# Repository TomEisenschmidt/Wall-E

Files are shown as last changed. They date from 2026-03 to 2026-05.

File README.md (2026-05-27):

# Projet IOT MAKER

L'objectif de ce projet est de réaliser un robot intéractif en modélisant les pièces en 3D et en utilisant des composants arduino pour gérer la partie intelligente.

## Fonctionnalitées : 

Wall E peut :
- Se déplacer
- Ouvrir et fermer sa trappe
- Déplacer ses bras d'avant en arrière
- Afficher des informations sur son écran

## Matériel : 

- 2 moteurs DC
- 1 carte de contrôle moteur L298N
- 4 batteries 18650
- 2 servo-moteur SG90
- 1 servo-moteur MG996R
- 1 capteur ultrason HC-SR04
- 1 écran LCD

## Impression 3D

- Face avant du robot (espace vide pour la porte), contient le servo de la porte
- Porte avant
- Face arrière
- Plaque gauche
- Plaque droite
- Sol
- Plaque du haut
- Tête
- Cache moteurs
- Support pour les roues non motrices

## Approche de la conception

Le projet repose sur sa composante modulable.
En effet, les différentes parties sont fixés entre elles grâce à des vis M4, permettant de démonter et modifier certaines parties facilement.
La face avant contient la porte et se visse au sol et les plaques droite/gauche se vissent à la face avant/arrière.
La seule exception repose pour les parties en dessous du robot et la tête, celles-ci sont fixées à l'aide de colle forte (élément non destiné à être changés).

Ainsi, cette approche permet la modification et le dépannage facile en permettant de démonter les plaques du chassis centrales contenant les différents composants.

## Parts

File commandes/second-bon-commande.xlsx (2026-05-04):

Amazon |  |  |  |  |  | Gotronic |  |  |  |  | Conrad
Composant | Lien | Quantité | Prix/Unitaire | Total/produit |  | Composant | Lien | Quantité | Prix/Unitaire | Total/produit | Composant | Lien | Quantité | Prix/Unitaire | Total/produit
M4 Vis Boulons et Écrous et Rondelles Set | Kit_Vis (https://www.amazon.fr/Boulons-Rondelles-Hexagonale-Inoxydable-Assortiment/dp/B0DQTTY82R) | 1 | 10.99 | 10.99 |  | Servo Moteur Linéaire | servomoteur-lineaire (https://www.gotronic.fr/art-servomoteur-lineaire-2595-30098.htm) | 2 | 9.6 | 19.2 | Carte de dévelopement moteur | Motodriver (https://www.conrad.fr/fr/p/joy-it-sbc-motodriver2-carte-de-developpement-1-pc-s-1573541.html?experience=b2c) | 1 | 5.99 | 5.99
Colle Forte | Colle (https://www.amazon.fr/UHU-Colle-tout-super-transparente/dp/B004QMADSW) | 1 | 3.69 | 3.69 |  | US HC-SR04 | detection-us (https://www.gotronic.fr/art-module-de-detection-us-hc-sr04-20912.htm) | 1 | 3.9 | 3.9 |  |  |  |  | 0
Pince à dénudé | Pince (https://www.amazon.fr/Bosch-Professional-1600A01V03-Chrome-Vanadium-softgrip/dp/B095SV614X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) | 1 | 16.99 | 16.99 |  | Motoréducteur | Moteur (https://www.gotronic.fr/art-motoreducteur-2-axes-3487-27384.htm) | 2 | 41.5 | 83 |  |  |  |  | 0
Support HC-SR04 | Support Capteur US (https://www.amazon.fr/Support-montage-capteur-ultrasons-intelligente/dp/B0848F4BF8) | 1 | 5.91 | 5.91 |  | Roues TT | Roues TT (https://www.gotronic.fr/art-roue-tout-terrain-120-mm-dg3cr-12401.htm) | 4 | 7.9 | 31.6 |  |  |  |  | 0
Roue 6,8 cm | roues (https://www.gotronic.fr/art-roues-68x25-mm-49218.htm) | 4 | 2.5 | 10 |  |  |  |  |  | 0 |  |  |  |  | 0
 |  |  |  | 0 |  |  |  |  |  | 0 |  |  |  |  | 0
 |  |  |  | 0 |  |  |  |  |  | 0 |  |  |  |  | 0
 |  |  |  | 0 |  |  |  |  | Total | 137.7 |  |  |  | Total | 5.99
 |  |  |  | 0
 |  |  |  | 0
 |  |  |  | 0
 |  |  |  | 0
 |  |  |  | 0
 |  |  |  | 0
 |  |  | Total | 47.58
 |  |  |  | Total commande : | 191.27

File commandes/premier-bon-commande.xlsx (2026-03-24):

Amazon |  |  |  |  |  | Gotronic |  |  |  |  | Conrad
Composant | Lien | Quantité | Prix/Unitaire | Total/produit |  | Composant | Lien | Quantité | Prix/Unitaire | Total/produit | Composant | Lien | Quantité | Prix/Unitaire | Total/produit
Lot de 2 micro servo moteurs | Amazon (https://www.amazon.fr/HAXIHA-Servomoteur-Num%C3%A9rique-Engrenage-Pr%C3%A9cision/dp/B0F892P2WQ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) | 1 | 13.99 | 13.99 |  | Arduino Mega 2560 (board arduino) | gotronic (https://www.gotronic.fr/art-arduino-mega-2560-a000067-12421.htm) | 1 | 45.6 | 45.6 | Pile | conrad (https://www.conrad.fr/fr/p/voltcraft-vc-li-3-6-3000-pile-rechargeable-speciale-18650-flat-top-li-ion-3-6-v-3000-mah-1-pc-s-2749812.html) | 4 | 6.99 | 27.96
Support de batteries | Amazon (http://www.amazon.fr/GTIWUNG-Support-Batterie-Plastique-Rangement/dp/B08CY5LC8M) | 1 | 9.99 | 9.99 |  | 74HC595 (micro-controller) | gotronic (https://www.gotronic.fr/art-74hc595-10102.htm) | 1 | 3.9 | 3.9 |  |  |  |  | 0
 |  |  |  | 0 |  | Palonnier rond en métal avec vis | gotronic (https://www.gotronic.fr/art-palonnier-rond-25-dents-fk-rp-001-25851.htm) | 2 | 4.5 | 9 |  |  |  |  | 0
 |  |  |  | 0 |  |  |  |  |  | 0 |  |  |  |  | 0
 |  |  |  | 0 |  |  |  |  |  | 0 |  |  |  |  | 0
 |  |  |  | 0 |  |  |  |  |  | 0 |  |  |  |  | 0
 |  |  |  | 0 |  |  |  |  |  | 0 |  |  |  |  | 0
 |  |  |  | 0 |  |  |  |  | Total | 58.5 |  |  |  | Total | 27.96
 |  |  |  | 0
 |  |  |  | 0
 |  |  |  | 0
 |  |  |  | 0
 |  |  |  | 0
 |  |  |  | 0
 |  |  | Total | 23.98
 |  |  |  | Total commande : | 82.48

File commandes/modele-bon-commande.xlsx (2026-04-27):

Amazon |  |  |  |  |  | Gotronic |  |  |  |  | Conrad
Composant | Lien | Quantité | Prix/Unitaire | Total/produit |  | Composant | Lien | Quantité | Prix/Unitaire | Total/produit | Composant | Lien | Quantité | Prix/Unitaire | Total/produit
 |  |  |  | 0 |  |  |  |  |  | 0 |  |  |  |  | 0
 |  |  |  | 0 |  |  |  |  |  | 0 |  |  |  |  | 0
 |  |  |  | 0 |  |  |  |  |  | 0 |  |  |  |  | 0
 |  |  |  | 0 |  |  |  |  |  | 0 |  |  |  |  | 0
 |  |  |  | 0 |  |  |  |  |  | 0 |  |  |  |  | 0
 |  |  |  | 0 |  |  |  |  |  | 0 |  |  |  |  | 0
 |  |  |  | 0 |  |  |  |  |  | 0 |  |  |  |  | 0
 |  |  |  | 0 |  |  |  |  | Total | 0 |  |  |  | Total | 0
 |  |  |  | 0
 |  |  |  | 0
 |  |  |  | 0
 |  |  |  | 0
 |  |  |  | 0
 |  |  |  | 0
 |  |  | Total | 0
 |  |  |  | Total commande : | 0

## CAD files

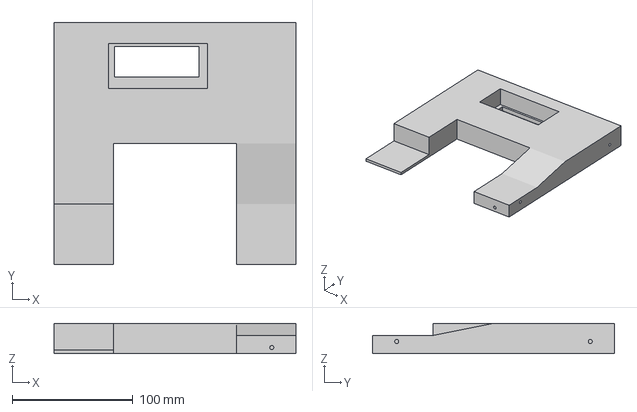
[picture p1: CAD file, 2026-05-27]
stéréolitographie/Bloc Avant & Arrière/Face Avant.3mf
200.0 x 200.0 x 25.0 mm

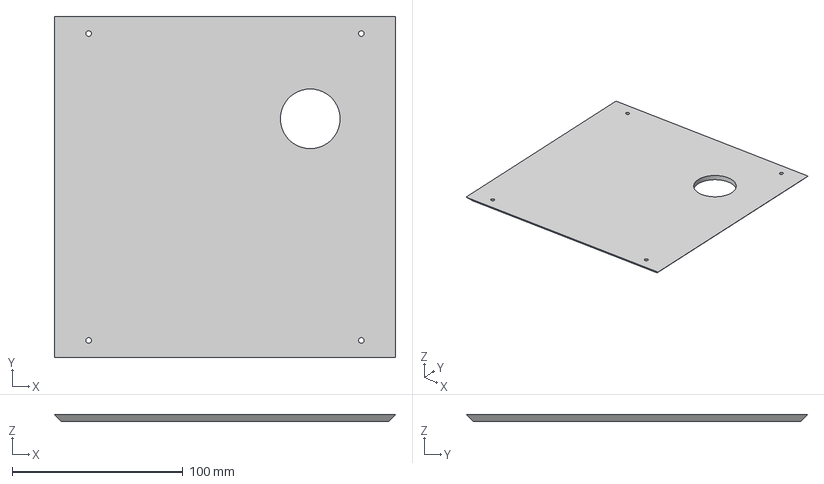
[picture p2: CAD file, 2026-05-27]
stéréolitographie/Bloc Côtés/BBG - 200x200 mm.3mf
200.0 x 200.0 x 4.00 mm

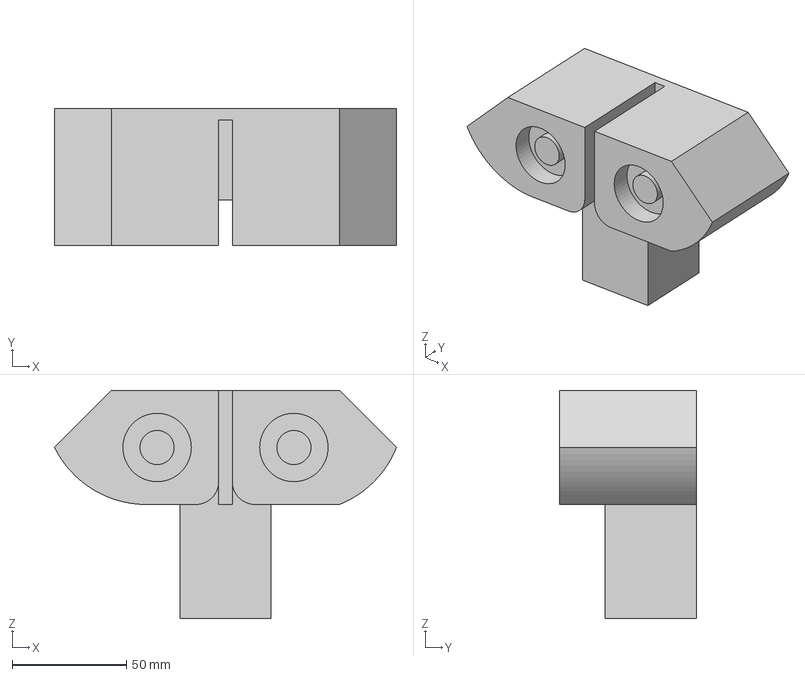
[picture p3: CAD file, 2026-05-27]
stéréolitographie/Bloc Plafond & Tête/Tête.3mf
150.0 x 60.0 x 100.0 mm

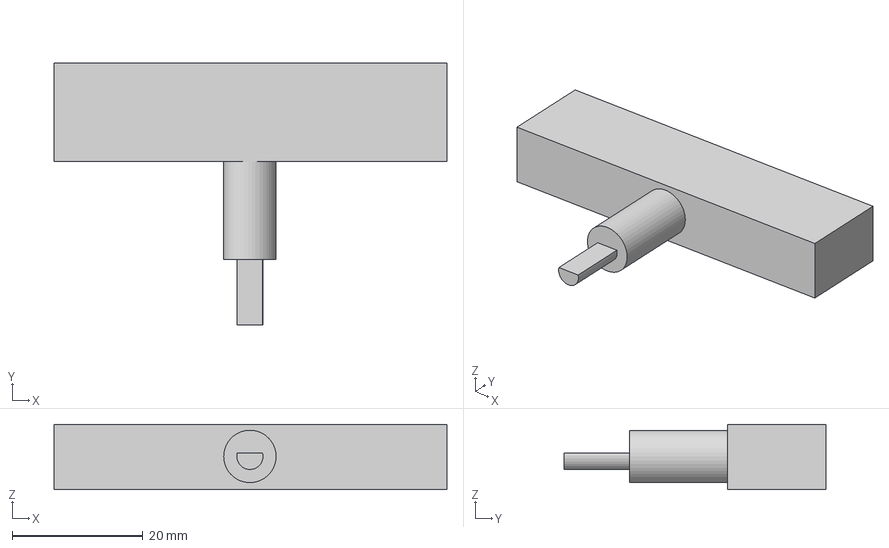
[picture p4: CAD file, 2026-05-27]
stéréolitographie/Bloc Sol & Roues/attache_moteur_4mm_diametres.3mf
60.0 x 40.0 x 10.00 mm

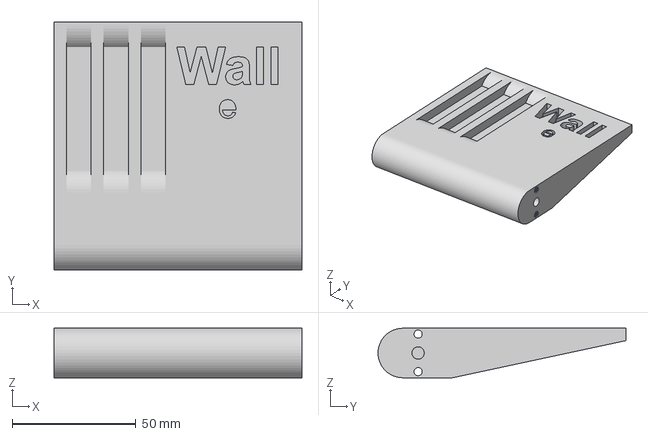
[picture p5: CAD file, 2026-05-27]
stéréolitographie/Bloc Avant & Arrière/Trappe.3mf
100.0 x 100.0 x 20.0 mm

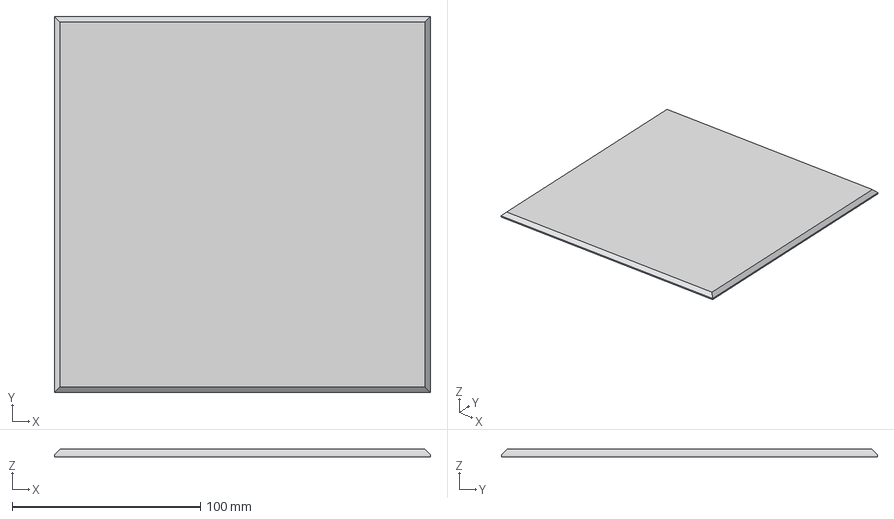
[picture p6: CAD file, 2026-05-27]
stéréolitographie/Bloc Plafond & Tête/plafond 200x200mm.3mf
200.0 x 200.0 x 4.00 mm

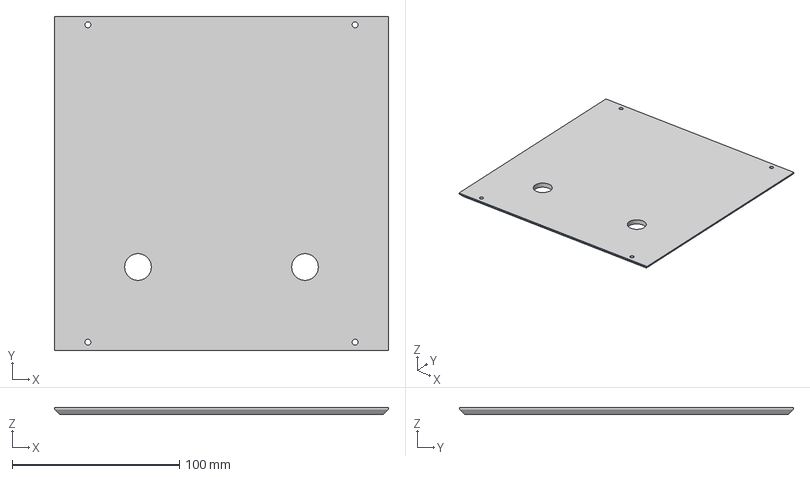
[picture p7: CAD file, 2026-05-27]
stéréolitographie/Bloc Sol & Roues/sol 200x200mm.3mf
200.0 x 200.0 x 4.00 mm

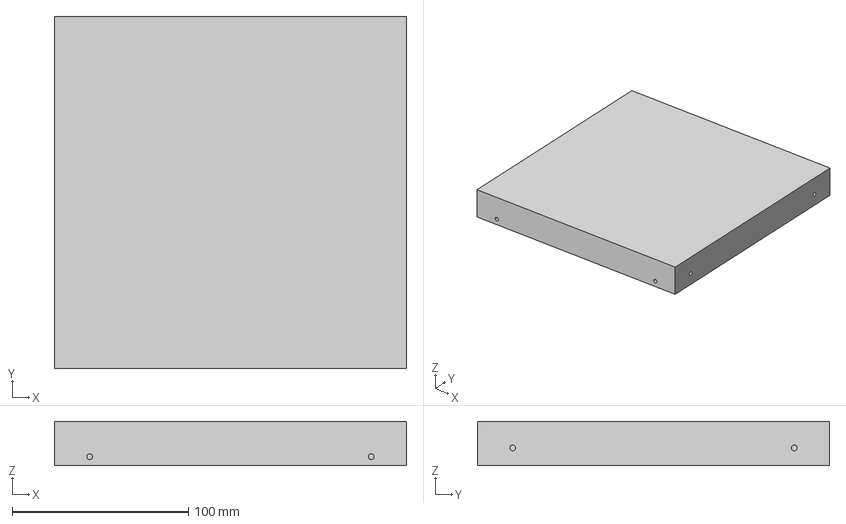
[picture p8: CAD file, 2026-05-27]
stéréolitographie/Bloc Avant & Arrière/Face Arrière.3mf
200.0 x 200.0 x 25.0 mm

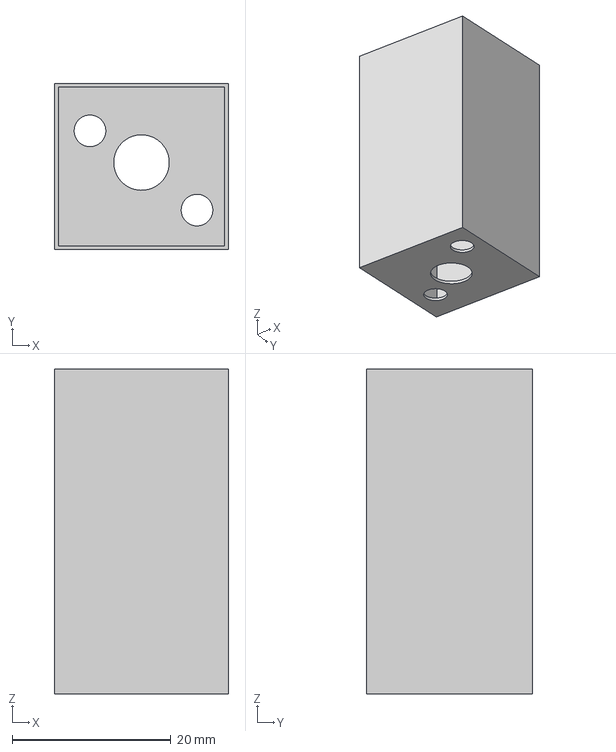
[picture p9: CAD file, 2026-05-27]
stéréolitographie/Bloc Sol & Roues/boitier_moteur_roue.3mf
22.0 x 21.0 x 41.0 mm

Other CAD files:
stéréolitographie/Bloc Côtés/BBD - 200x200 mm.3mf
Front Door 24-03-2026.f3d
Front Door Structure 25-03-2026.f3d
Modèles/Bloc Avant & Arrière/Back Structure.f3d
Modèles/Bloc Avant & Arrière/Front - Door.f3d
Modèles/Bloc Avant & Arrière/Front - Structure.f3d
Modèles/Bloc Bras/BBD - 200x200 mm.f3d
Modèles/Bloc Bras/BBG - 200x200 mm.f3d
Modèles/Bloc Plafond & Tête/plafond 200x200mm.f3d
Modèles/Bloc Plafond & Tête/tete_wall_e.f3d
Modèles/Bloc Sol & Chenille/Sol 200x200mm.f3d
Modèles/Bloc Sol & Chenille/attache_roue_4mm_diametres.f3d
Modèles/Bloc Sol & Chenille/boitier_moteur_roue.f3d
Modèles/Vision globale du cube central.f3d

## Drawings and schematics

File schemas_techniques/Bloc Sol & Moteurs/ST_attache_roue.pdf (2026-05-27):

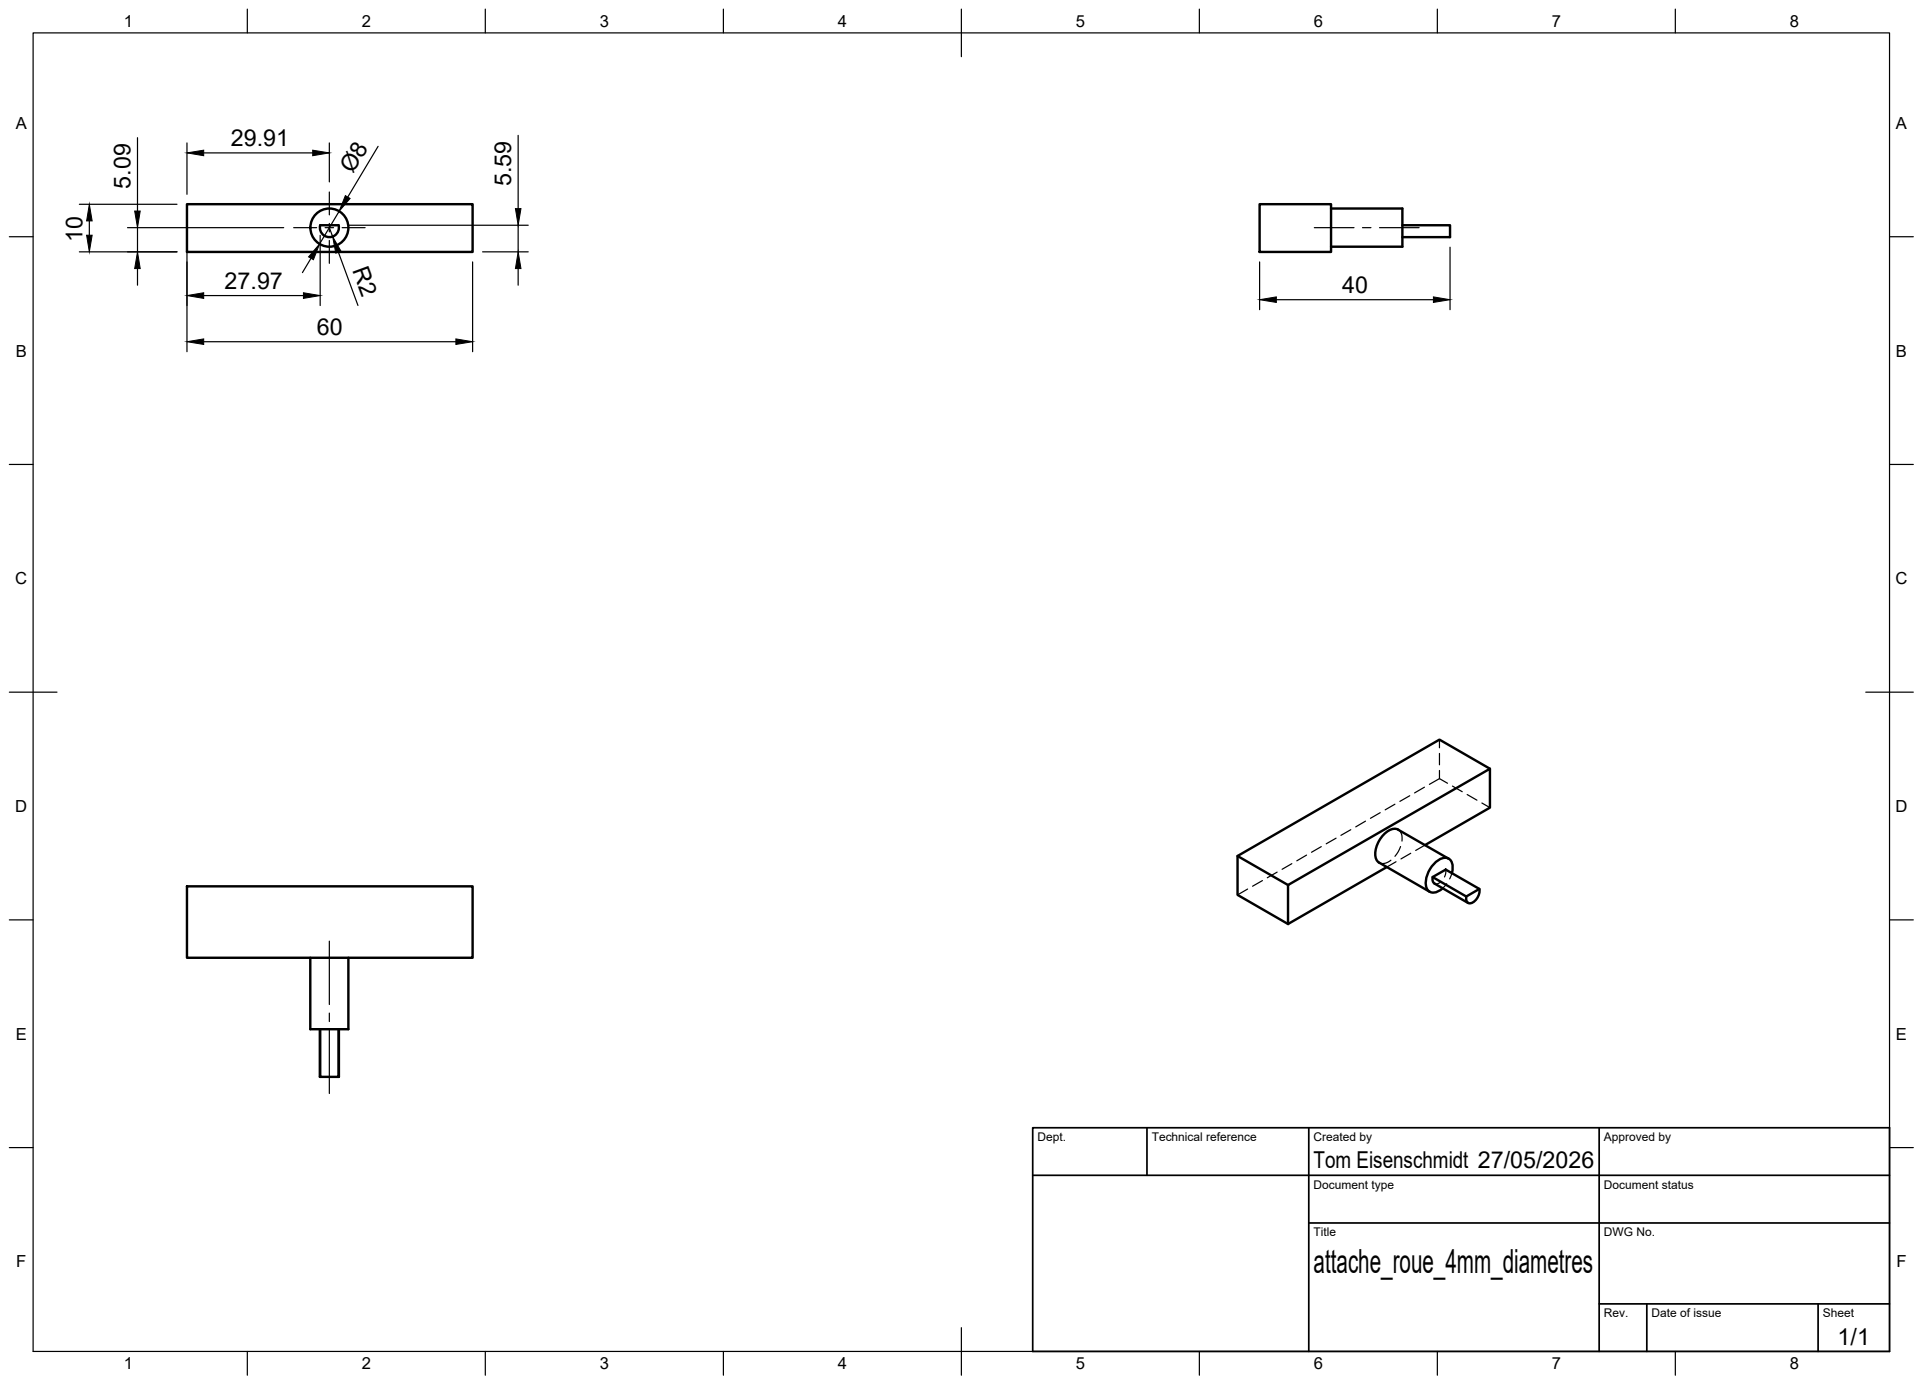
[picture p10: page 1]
Title; DWG No.; Rev.; Date of issue; Sheet

Dept. | Technical reference | Created by Tom Eisenschmidt 27/05/2026 | Approved by

Document type | Document status

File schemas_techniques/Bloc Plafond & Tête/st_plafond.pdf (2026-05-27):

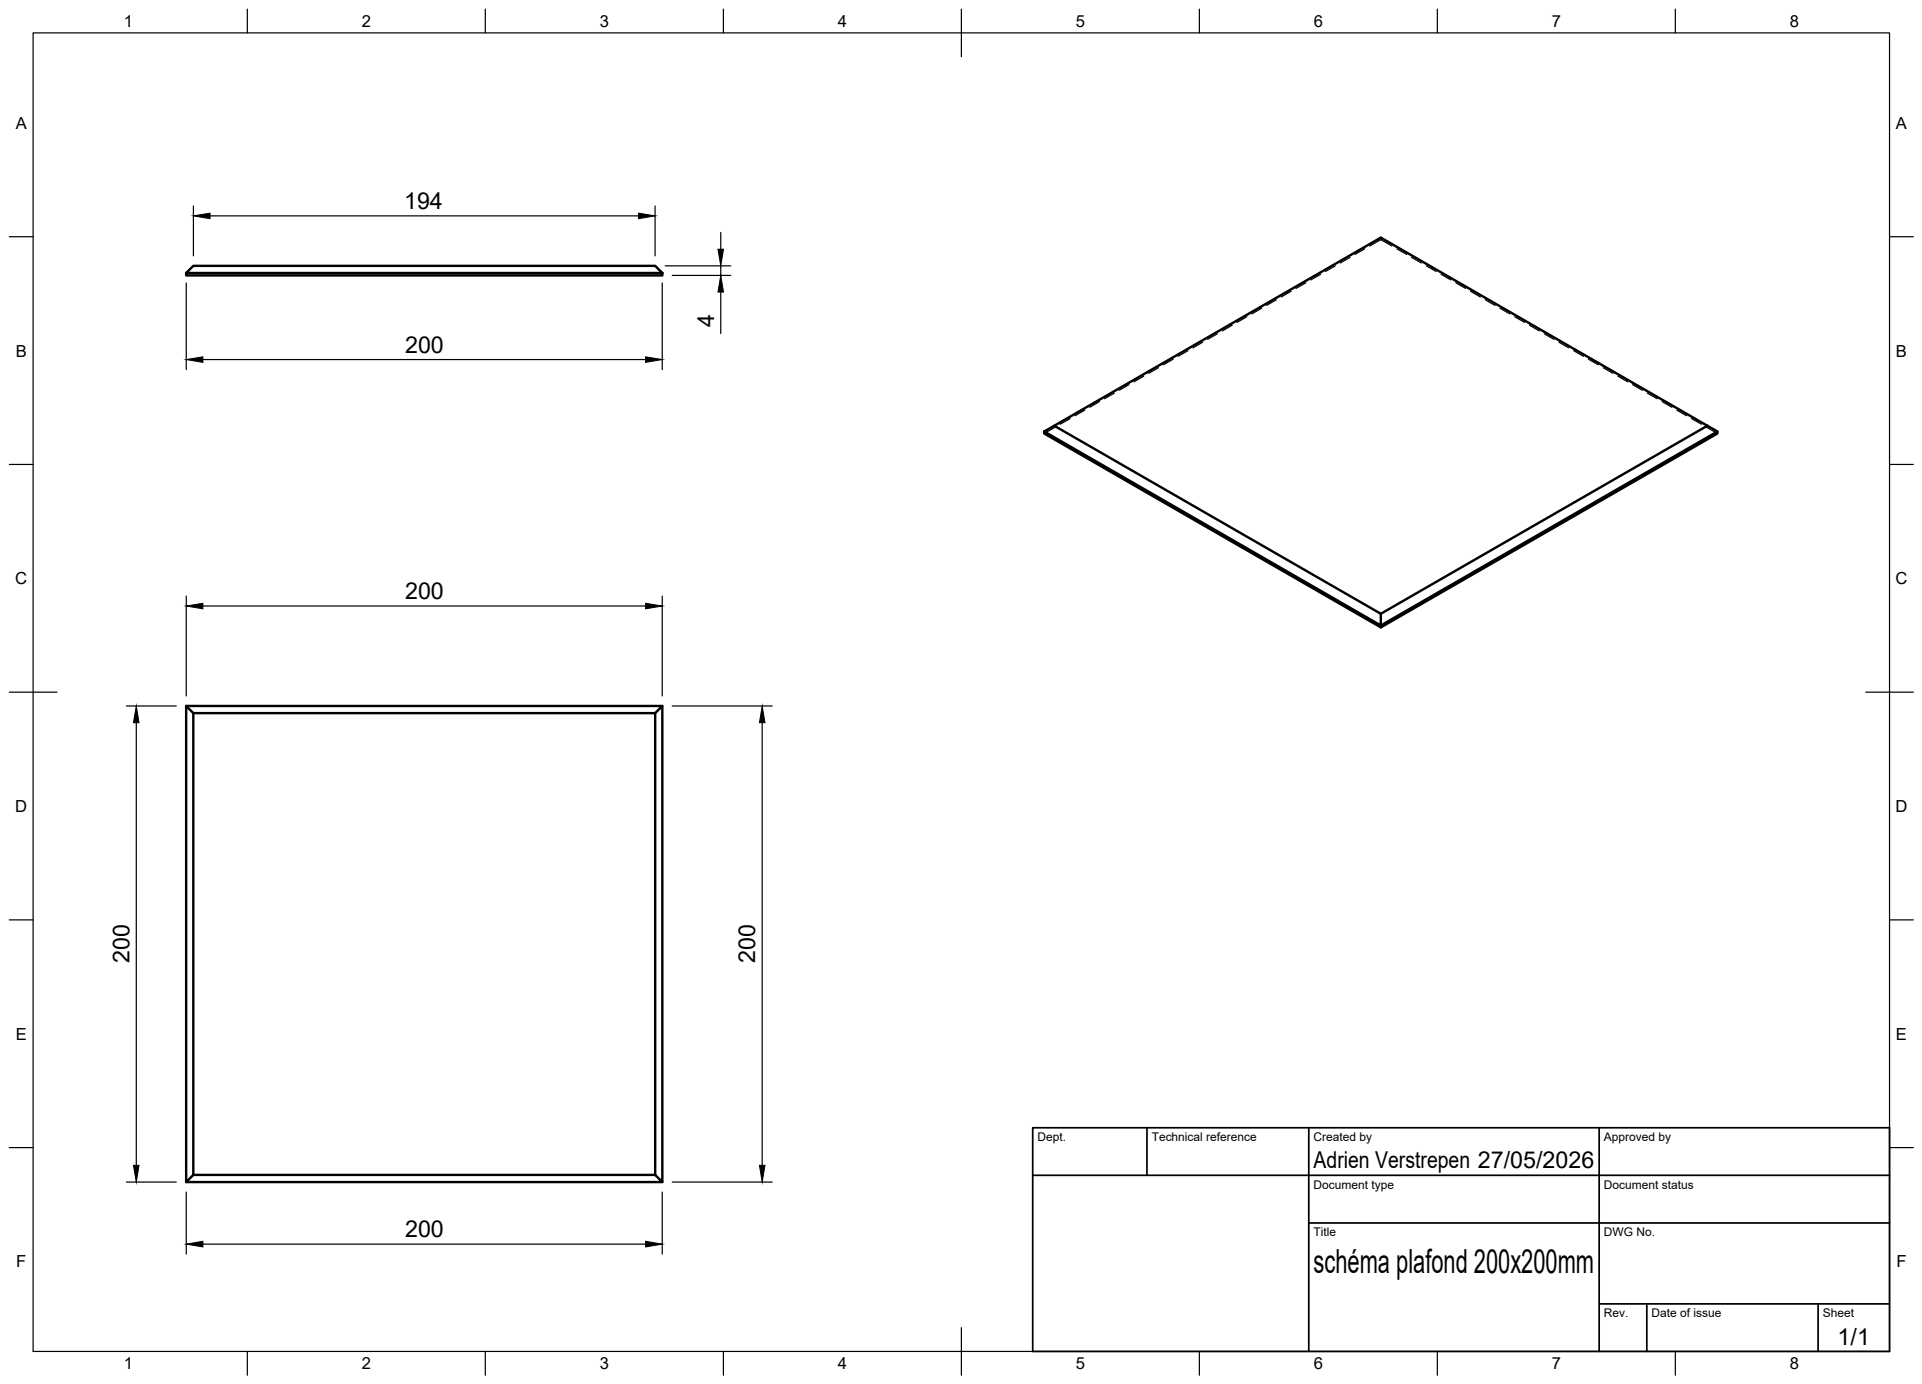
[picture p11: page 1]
Title; DWG No.; Rev.; Date of issue; Sheet; schéma plafond 200x200mm

Dept. | Technical reference | Created by Adrien Verstrepen 27/05/2026 | Approved by

Document type | Document status

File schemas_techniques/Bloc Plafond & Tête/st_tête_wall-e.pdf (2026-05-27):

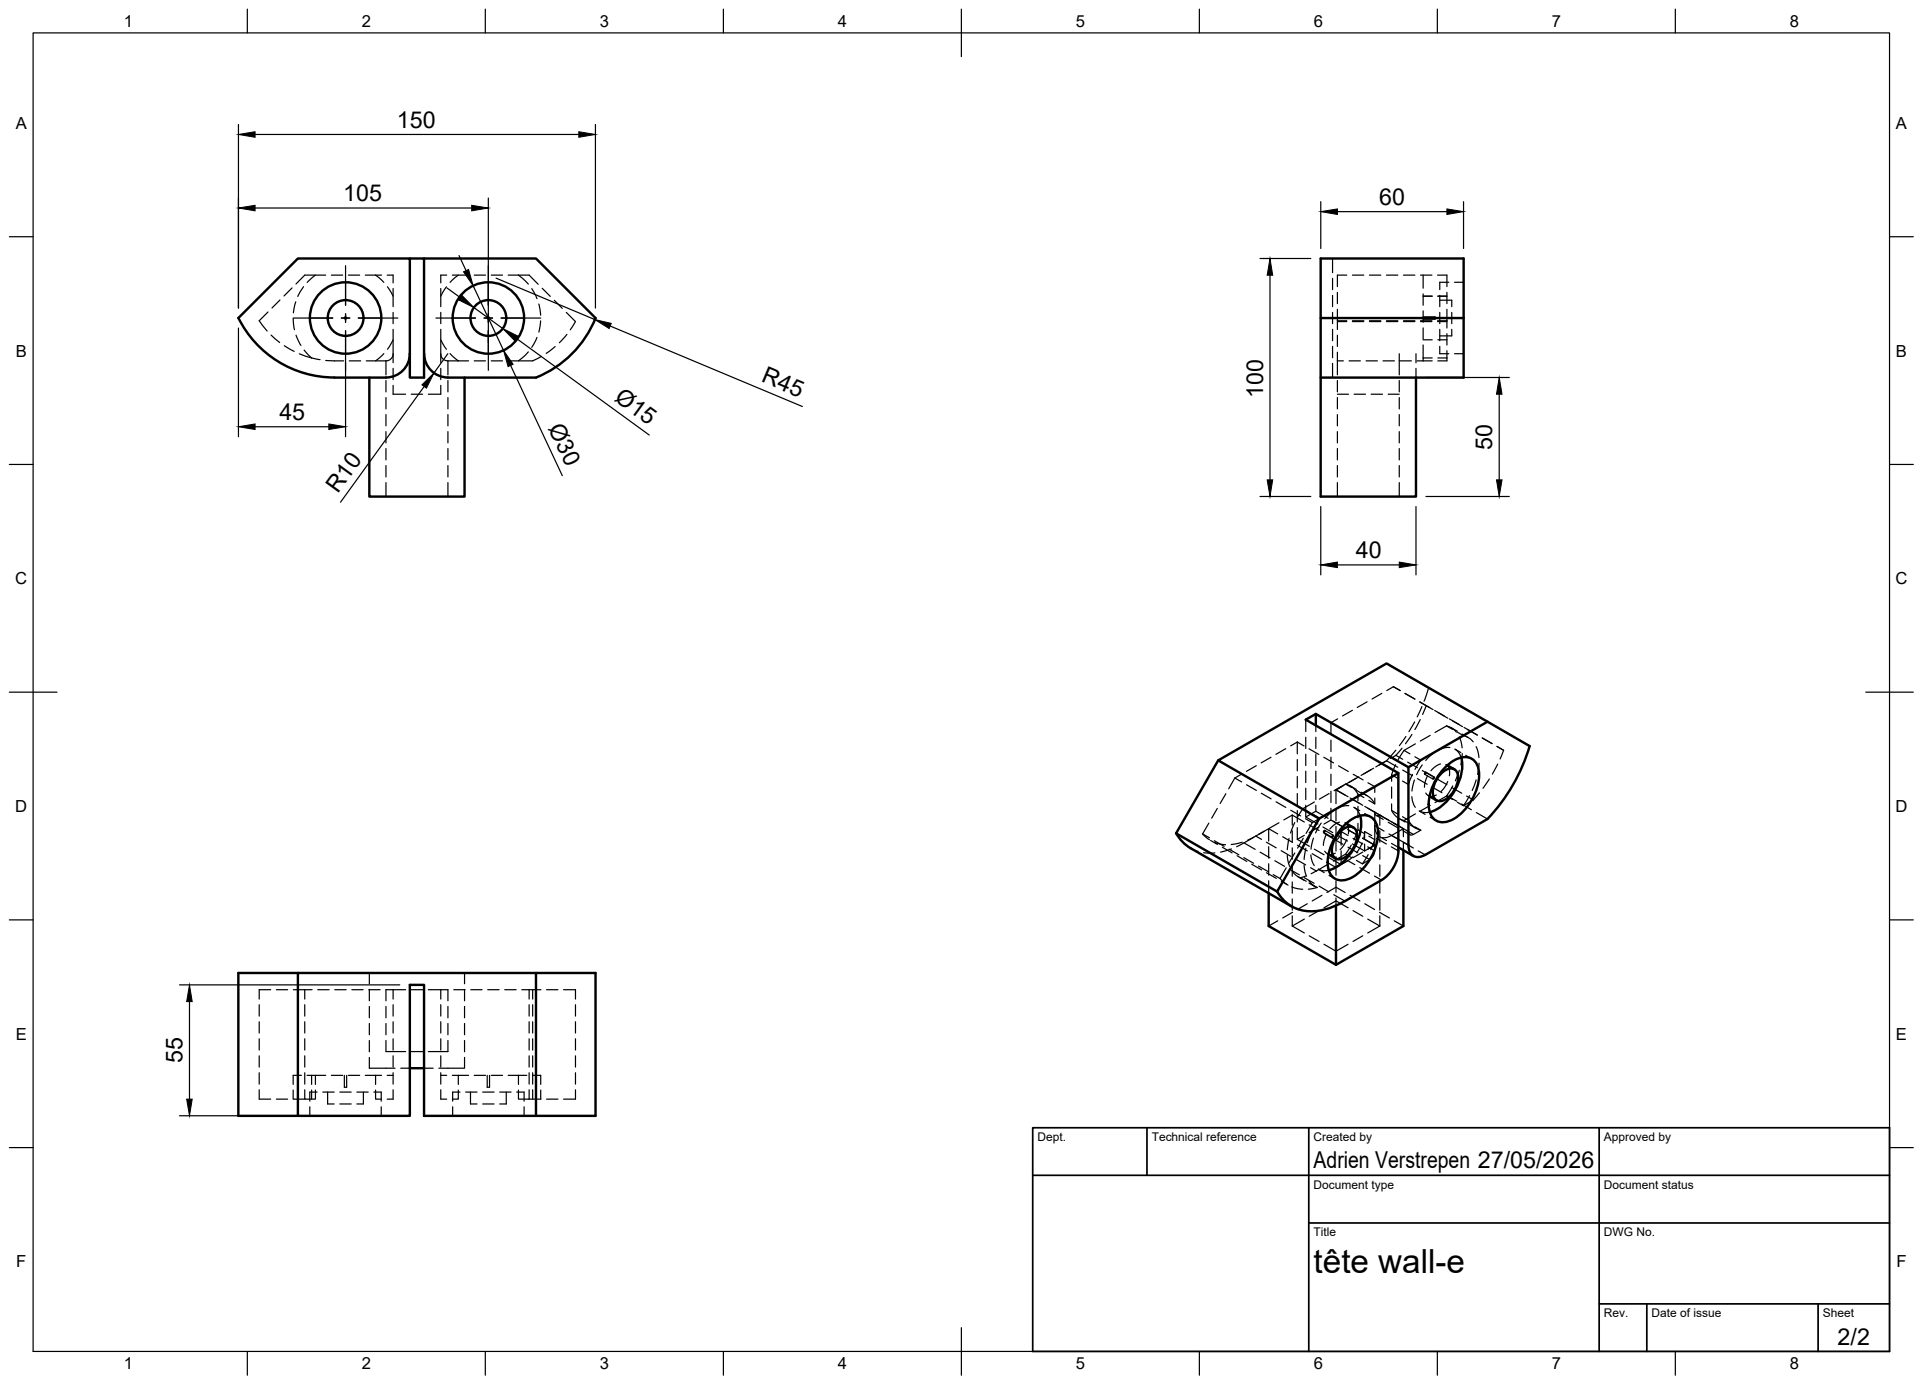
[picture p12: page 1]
Title; DWG No.; Rev.; Date of issue; Sheet; tête wall-e

Dept. | Technical reference | Created by Adrien Verstrepen 27/05/2026 | Approved by

Document type | Document status

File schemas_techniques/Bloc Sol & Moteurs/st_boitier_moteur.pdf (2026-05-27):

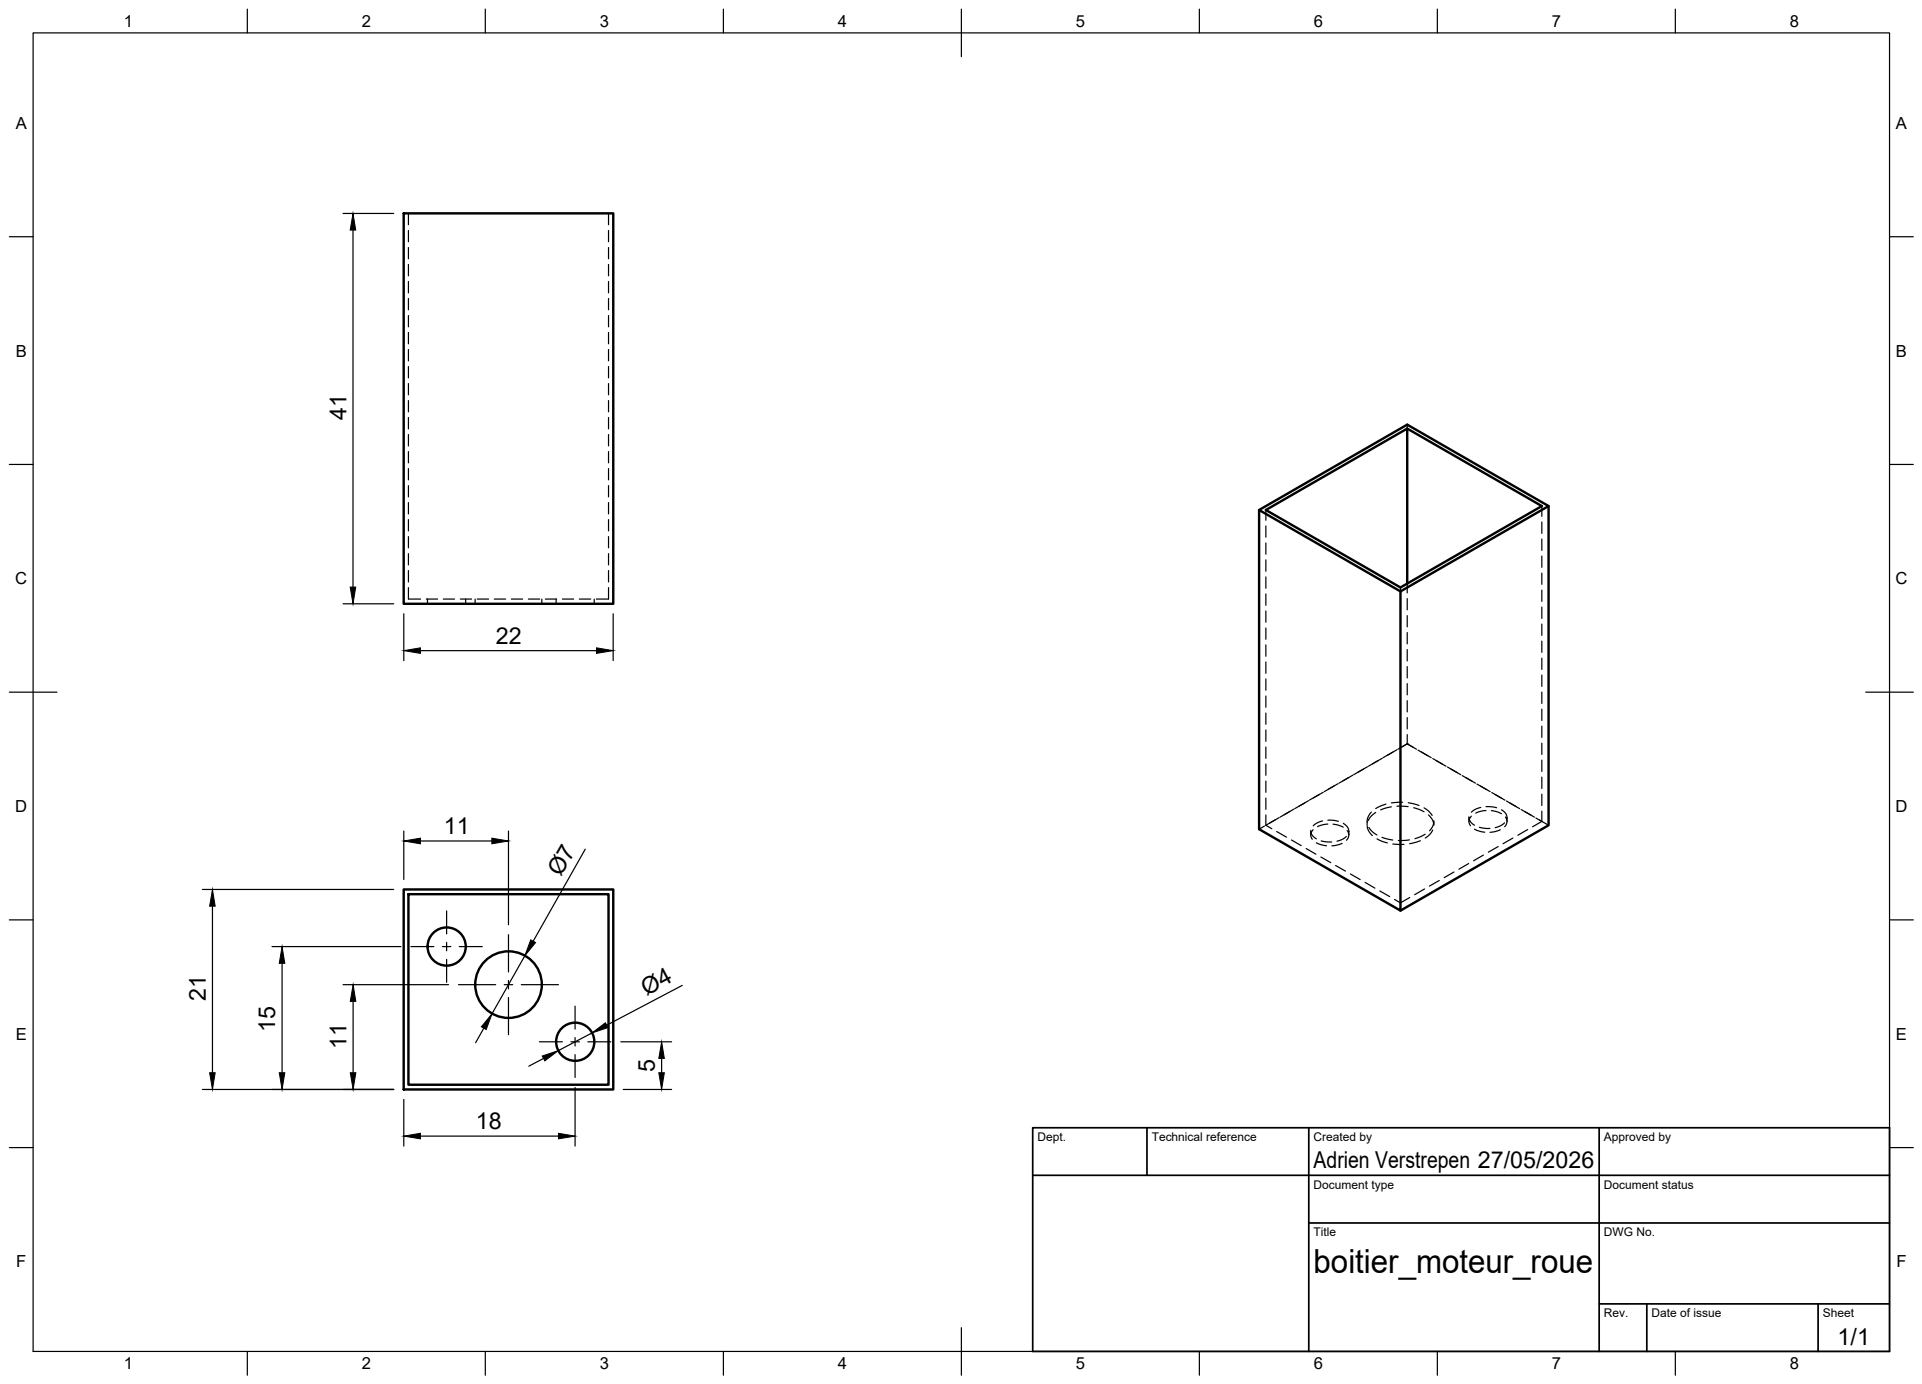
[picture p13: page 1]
Title; DWG No.; Rev.; Date of issue; Sheet; Adrien Verstrepen 41

Dept. | Technical reference | Created by 27/05/2026 | Approved by

Document type | Document status

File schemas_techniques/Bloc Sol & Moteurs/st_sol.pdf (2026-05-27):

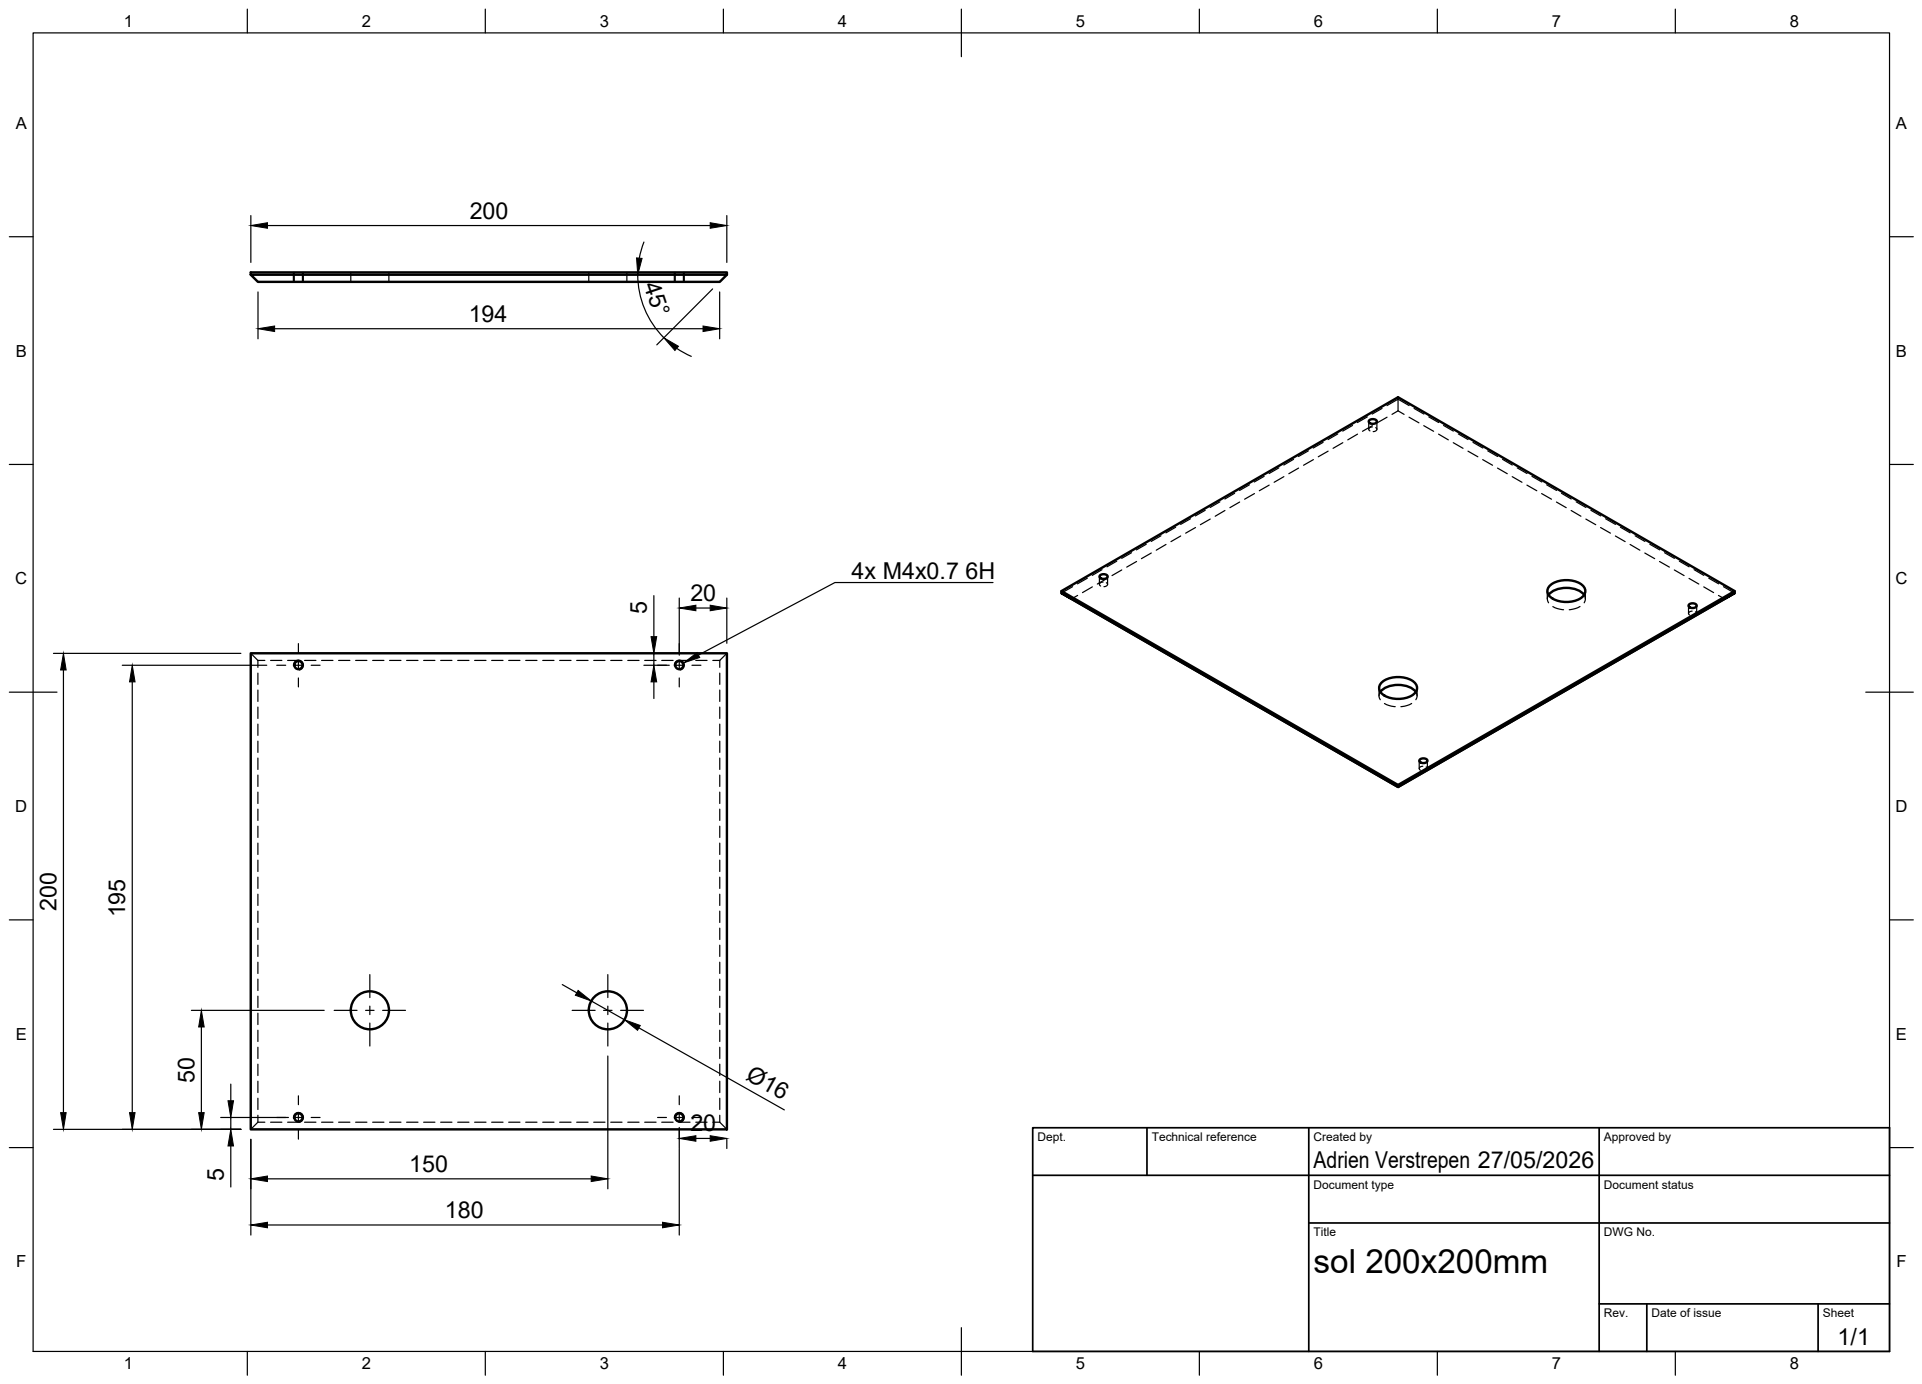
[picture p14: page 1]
Title; DWG No.; Rev.; Date of issue; Sheet; sol 200x200mm

Dept. | Technical reference | Created by Adrien Verstrepen 27/05/2026 | Approved by

Document type | Document status

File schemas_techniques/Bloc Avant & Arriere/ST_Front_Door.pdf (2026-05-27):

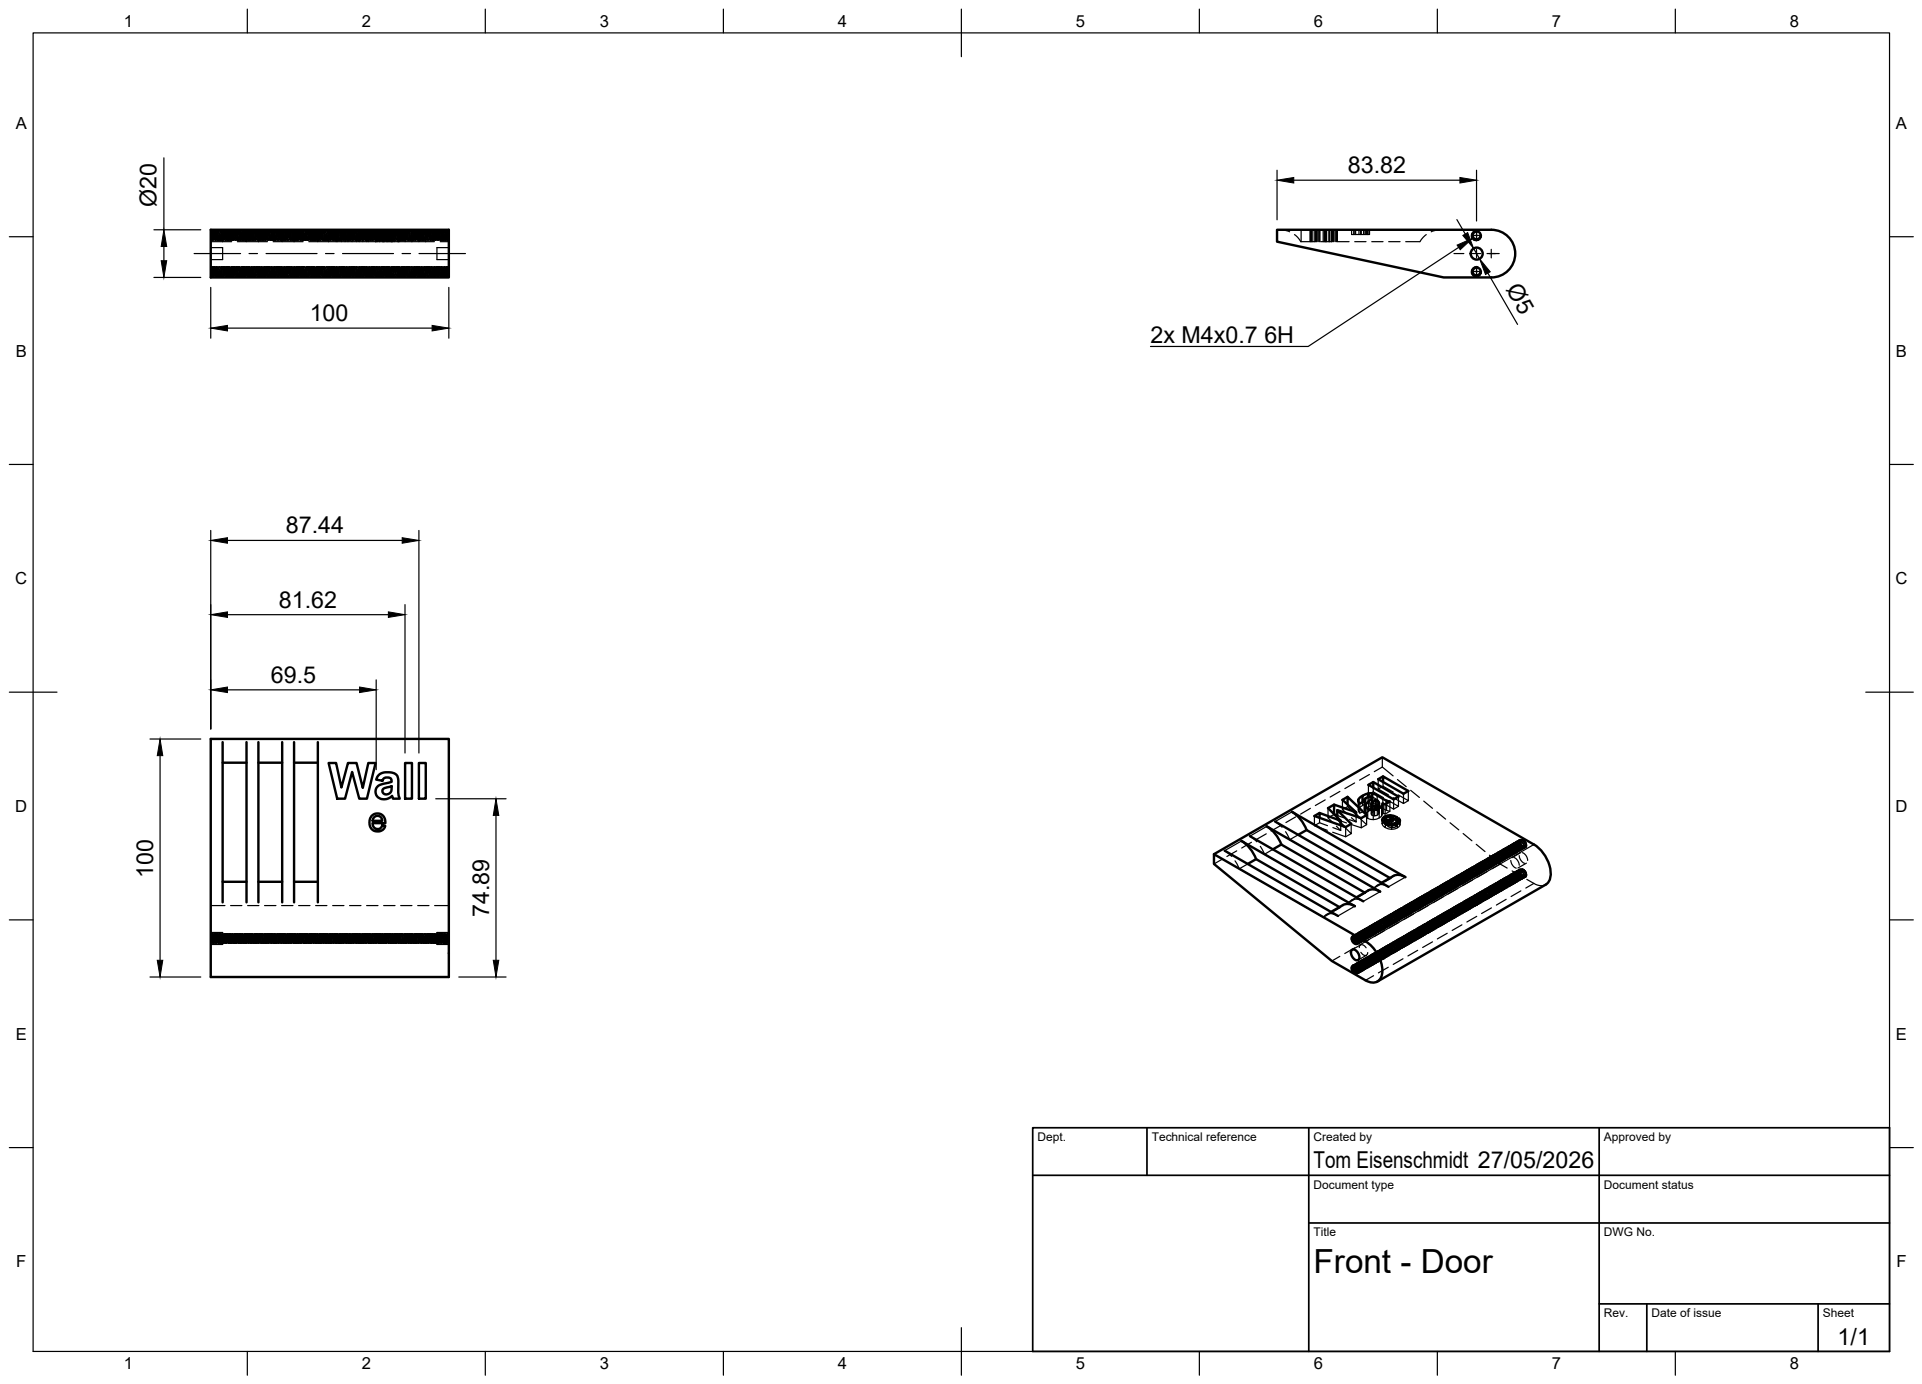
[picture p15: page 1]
Dept.; Technical reference; Created by; Approved by; Document type; Document status; Title; DWG No.; Rev.; Date of issue; Sheet; Front - Door; Tom Eisenschmidt

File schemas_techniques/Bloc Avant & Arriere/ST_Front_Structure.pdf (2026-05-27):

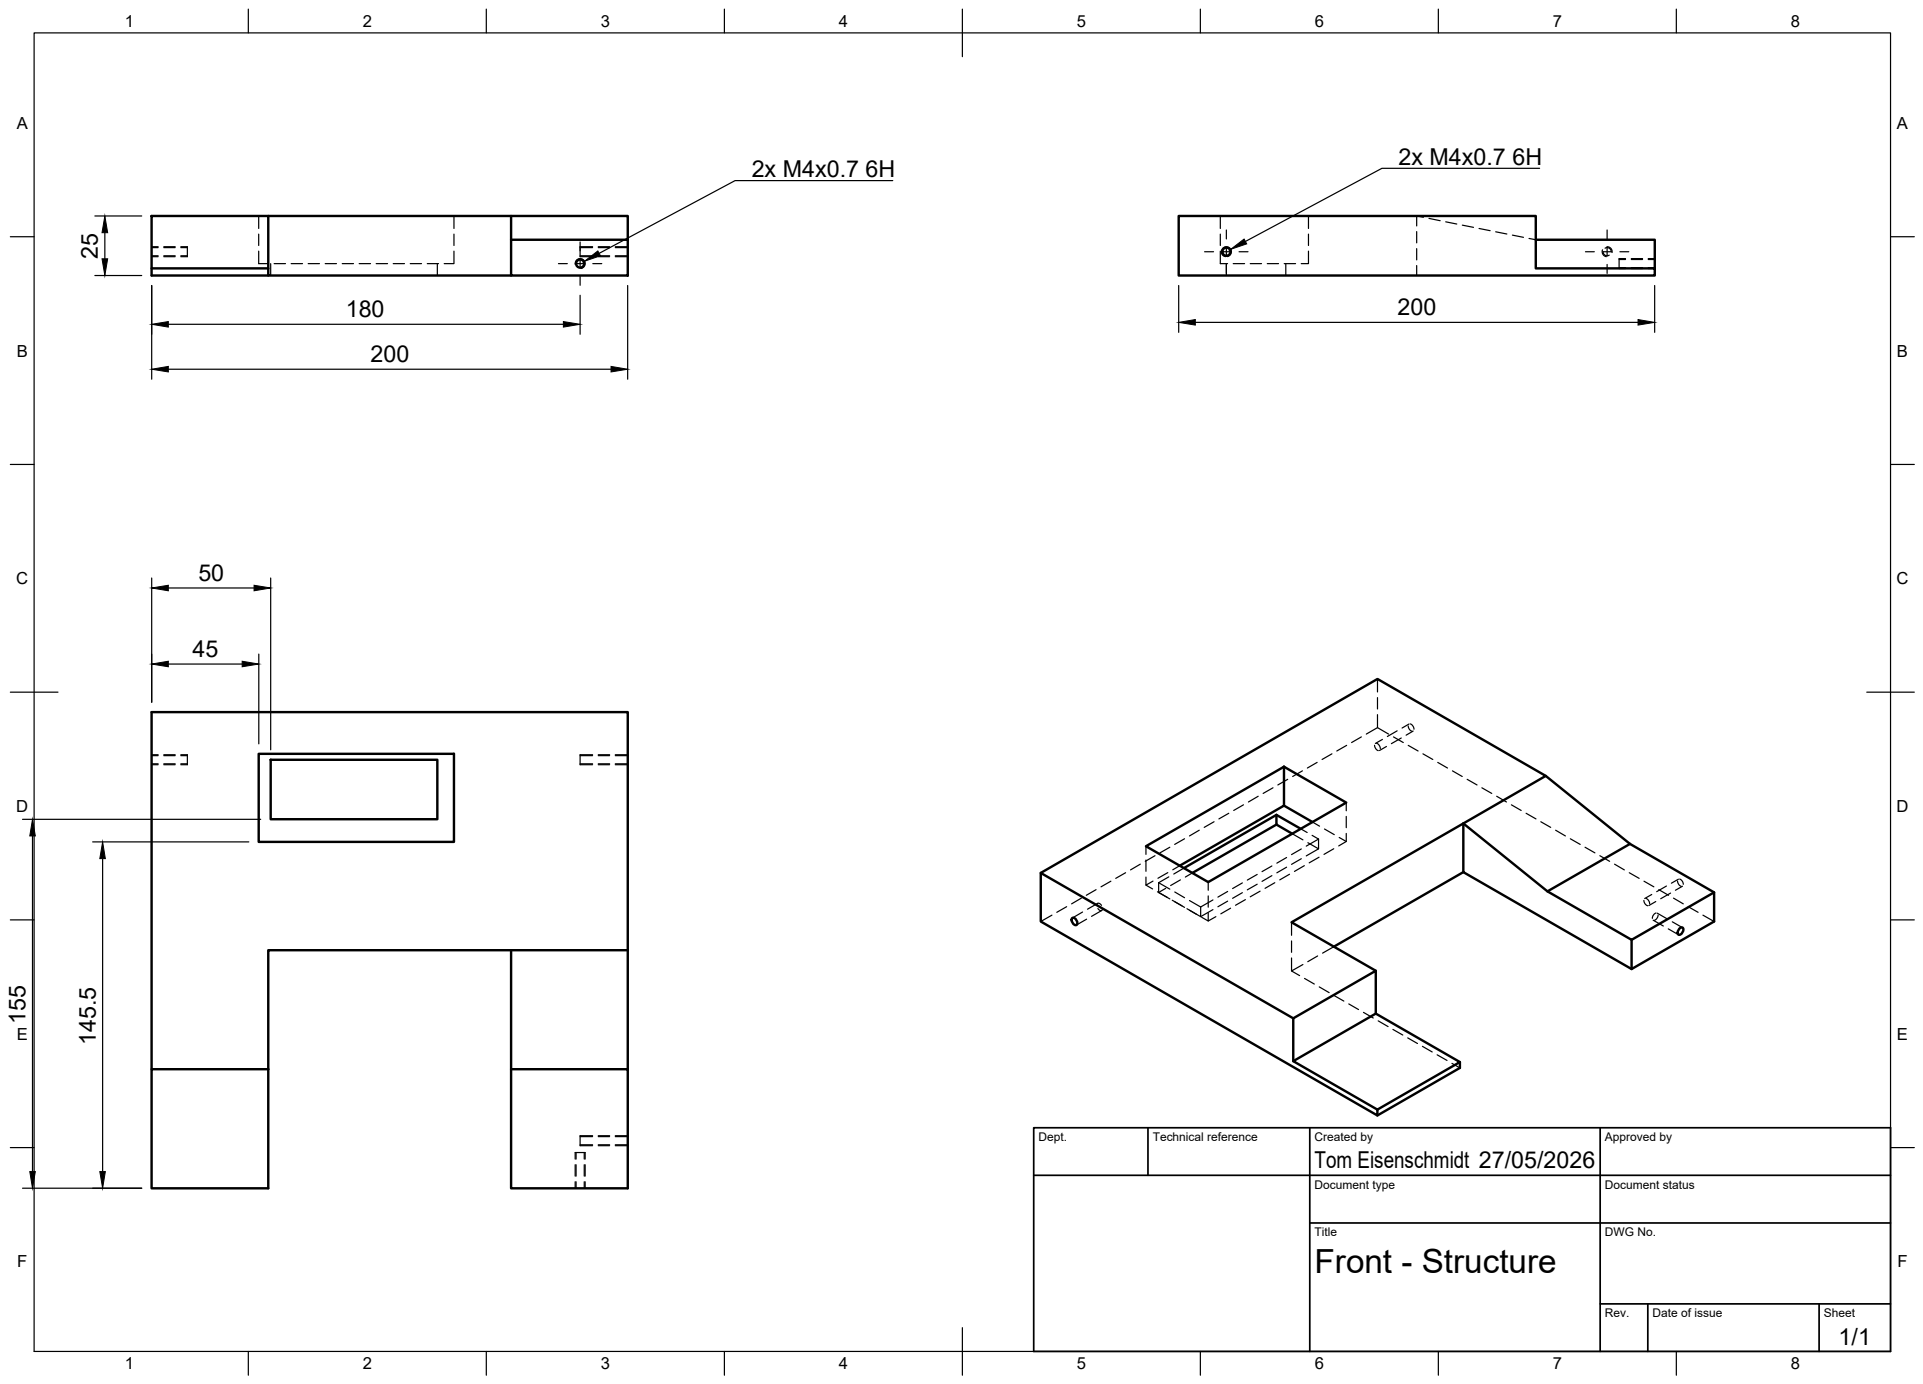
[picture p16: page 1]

Dept. | Technical reference | Created by Tom Eisenschmidt 27/05/2026 | Approved by

Document type | Document status

Title Front - Structure | DWG No.

Rev. | Date of issue | Sheet 1/1

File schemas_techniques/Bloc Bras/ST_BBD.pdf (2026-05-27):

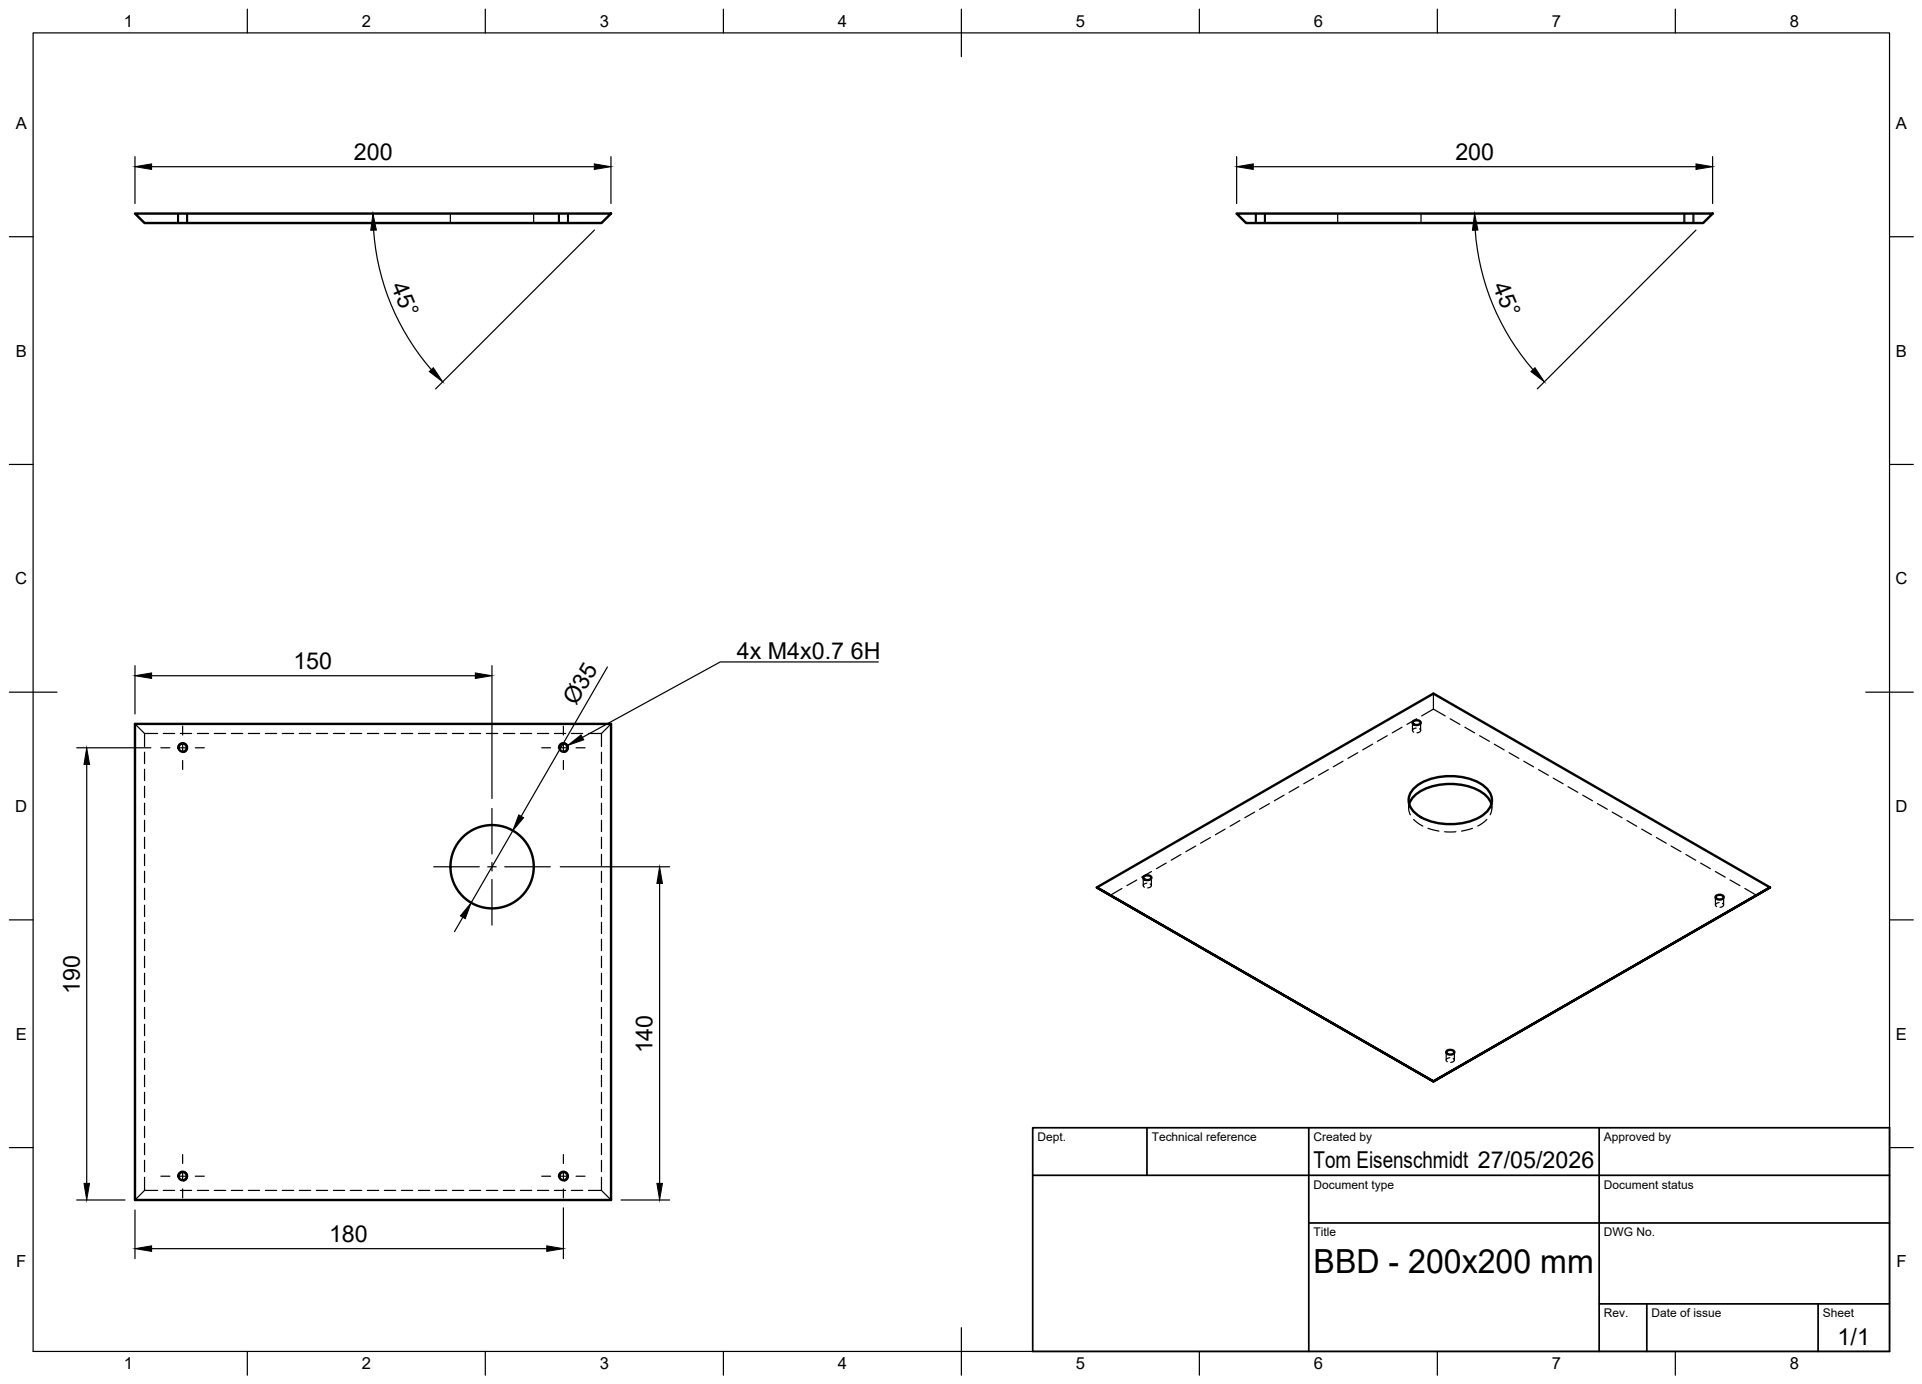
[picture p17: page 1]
Title; DWG No.; Rev.; Date of issue; Sheet; BBD - 200x200 mm

Dept. | Technical reference | Created by Tom Eisenschmidt 27/05/2026 | Approved by

Document type | Document status

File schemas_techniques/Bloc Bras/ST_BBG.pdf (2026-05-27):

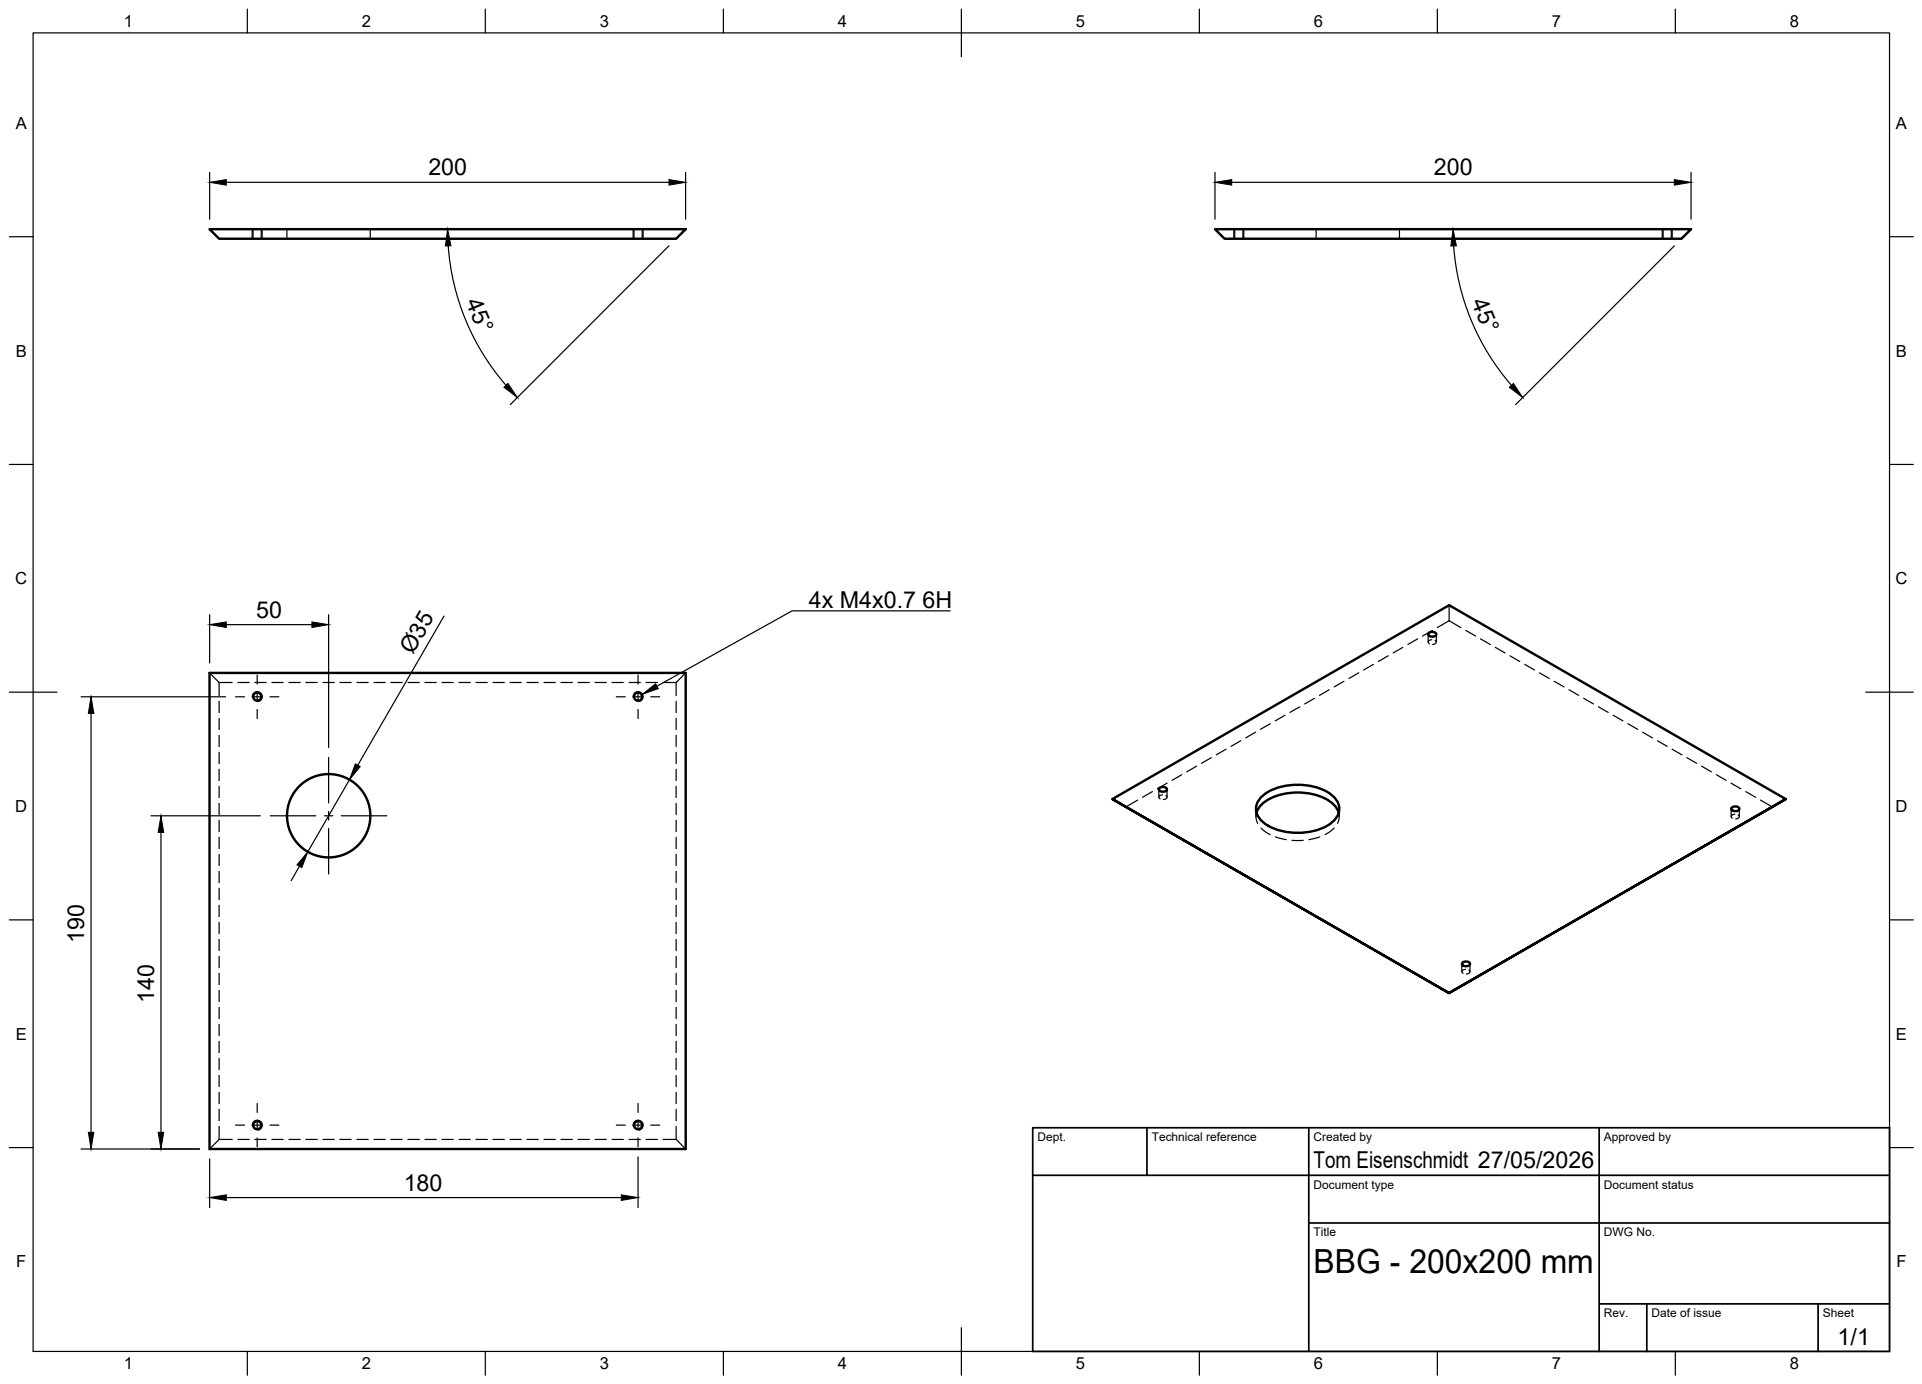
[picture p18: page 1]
Title; DWG No.; Rev.; Date of issue; Sheet; BBG - 200x200 mm

Dept. | Technical reference | Created by Tom Eisenschmidt 27/05/2026 | Approved by

Document type | Document status

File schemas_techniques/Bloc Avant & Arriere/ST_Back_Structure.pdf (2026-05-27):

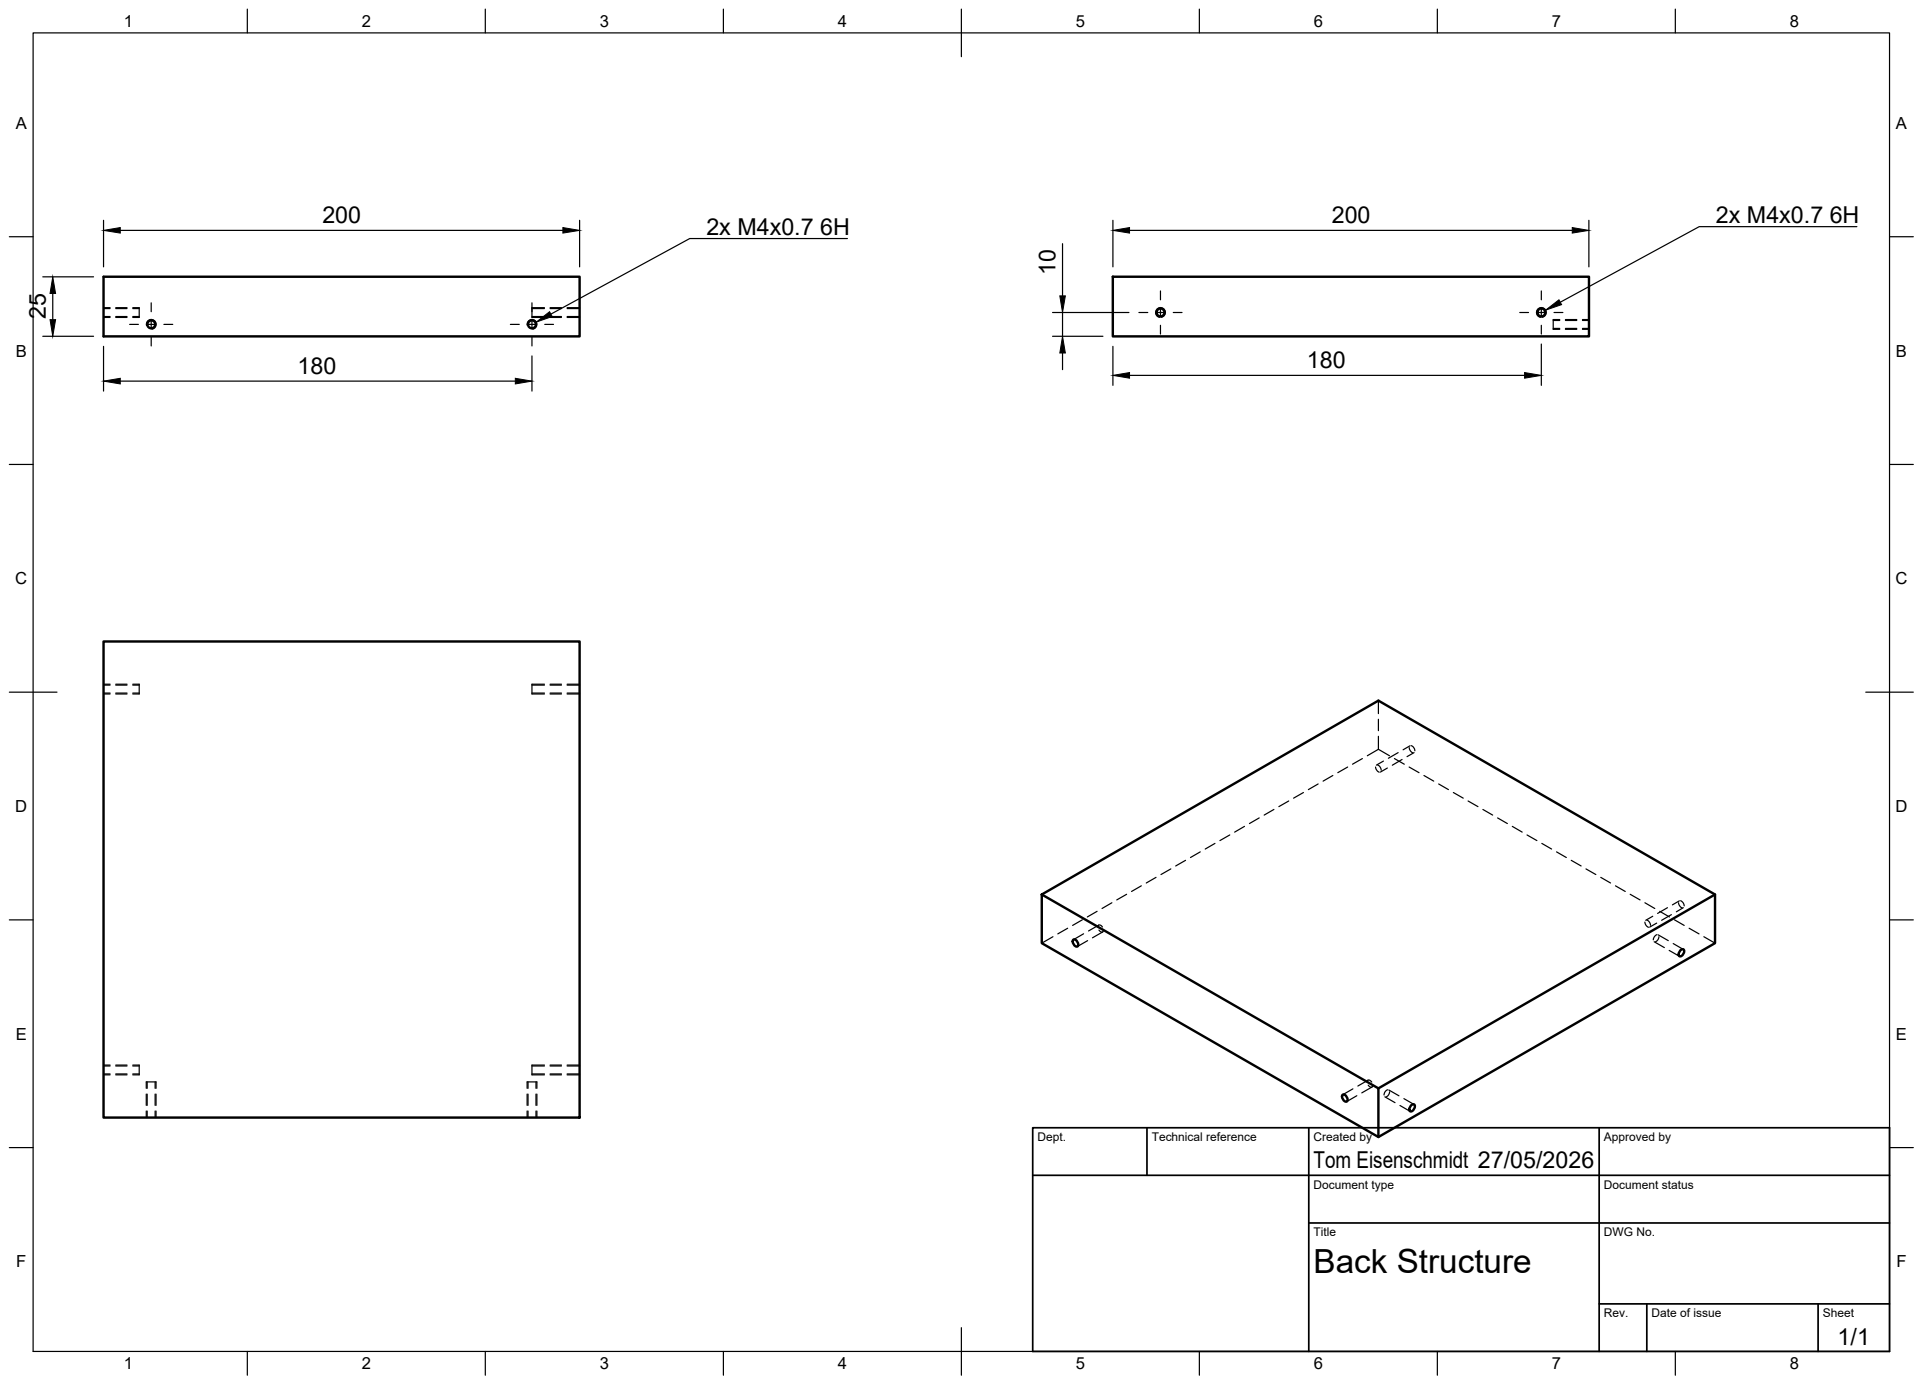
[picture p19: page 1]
Title; DWG No.; Rev.; Date of issue; Sheet; Back Structure

Dept. | Technical reference | Created by Tom Eisenschmidt 27/05/2026 | Approved by

Document type | Document status

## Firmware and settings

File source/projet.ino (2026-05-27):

#include <Servo.h>
#include <LiquidCrystal.h>

// =========================
// L298N - MOTEURS
// =========================

// Moteur gauche
const int IN1 = 2;
const int IN2 = 3;
const int ENA = 4;

// Moteur droit
const int IN3 = 5;
const int IN4 = 6;
const int ENB = 7;

// =========================
// CAPTEUR ULTRASON
// =========================

const int PIN_TRIG = 9;
const int PIN_ECHO = 8;

// =========================
// SERVOS
// =========================

// Porte
const int SERVO_PORTE = 11;

// Bras
const int SERVO_BRAS_GAUCHE = 26;
const int SERVO_BRAS_DROIT = 27;

Servo porte;
Servo brasGauche;
Servo brasDroit;

// =========================
// LCD 16x2
// RS, E, D4, D5, D6, D7
// =========================

const int LCD_RS = 30;
const int LCD_E  = 31;
const int LCD_D4 = 32;
const int LCD_D5 = 33;
const int LCD_D6 = 34;
const int LCD_D7 = 35;

LiquidCrystal lcd(
  LCD_RS,
  LCD_E,
  LCD_D4,
  LCD_D5,
  LCD_D6,
  LCD_D7
);

// =========================
// CONFIG
// =========================

const int DISTANCE_OBSTACLE = 20;

const int VITESSE_AVANCE = 160;
const int VITESSE_TOURNER = 120;

// Porte
const int ANGLE_PORTE_FERMEE = 140;
const int ANGLE_PORTE_OUVERTE = 15;

// Bras
const int ANGLE_BRAS_REPOS_G = 20;
const int ANGLE_BRAS_REPOS_D = 160;

const int ANGLE_BRAS_ACTIF_G = 90;
const int ANGLE_BRAS_ACTIF_D = 90;

// =========================
// SERVOS
// =========================

void ouvrirPorte() {
  porte.write(ANGLE_PORTE_OUVERTE);
}

void fermerPorte() {
  porte.write(ANGLE_PORTE_FERMEE);
}

void brasRepos() {

  brasGauche.write(ANGLE_BRAS_REPOS_G);
  brasDroit.write(ANGLE_BRAS_REPOS_D);
}

void brasActifs() {

  brasGauche.write(ANGLE_BRAS_ACTIF_G);
  brasDroit.write(ANGLE_BRAS_ACTIF_D);
}

// =========================
// ULTRASON
// =========================

long mesurerDistanceCM() {

  digitalWrite(PIN_TRIG, LOW);
  delayMicroseconds(2);

  digitalWrite(PIN_TRIG, HIGH);
  delayMicroseconds(10);

  digitalWrite(PIN_TRIG, LOW);

  long duree = pulseIn(PIN_ECHO, HIGH, 30000);

  if (duree == 0) {
    return -1;
  }

  return duree / 58;
}

// =========================
// LCD
// =========================

void afficherLCD(long distance) {

  lcd.clear();

  lcd.setCursor(0, 0);
  lcd.print("Distance:");

  lcd.setCursor(10, 0);

  if (distance < 0) {
    lcd.print("---");
  } else {
    lcd.print(distance);
    lcd.print("cm");
  }

  lcd.setCursor(0, 1);

  if (distance > 0 && distance <= DISTANCE_OBSTACLE) {
    lcd.print("Obstacle !");
  } else {
    lcd.print("Avance");
  }
}

// =========================
// MOTEURS
// =========================

void moteurGauche(int vitesse, bool avant) {

  vitesse = constrain(vitesse, 0, 255);

  digitalWrite(IN1, avant ? HIGH : LOW);
  digitalWrite(IN2, avant ? LOW : HIGH);

  analogWrite(ENA, vitesse);
}

void moteurDroit(int vitesse, bool avant) {

  vitesse = constrain(vitesse, 0, 255);

  digitalWrite(IN3, avant ? HIGH : LOW);
  digitalWrite(IN4, avant ? LOW : HIGH);

  analogWrite(ENB, vitesse);
}

// =========================
// DEPLACEMENTS
// =========================

void avancer() {

  moteurGauche(VITESSE_AVANCE, true);
  moteurDroit(VITESSE_AVANCE, true);
}

void tournerDroite() {

  moteurGauche(VITESSE_AVANCE, true);
  moteurDroit(VITESSE_TOURNER, false);
}

void stopMoteurs() {

  analogWrite(ENA, 0);
  analogWrite(ENB, 0);

  digitalWrite(IN1, LOW);
  digitalWrite(IN2, LOW);

  digitalWrite(IN3, LOW);
  digitalWrite(IN4, LOW);
}

// =========================
// SETUP
// =========================

void setup() {

  Serial.begin(9600);

  // Moteurs
  pinMode(IN1, OUTPUT);
  pinMode(IN2, OUTPUT);
  pinMode(ENA, OUTPUT);

  pinMode(IN3, OUTPUT);
  pinMode(IN4, OUTPUT);
  pinMode(ENB, OUTPUT);

  // Ultrason
  pinMode(PIN_TRIG, OUTPUT);
  pinMode(PIN_ECHO, INPUT);

  // Servos
  porte.attach(SERVO_PORTE);
  brasGauche.attach(SERVO_BRAS_GAUCHE);
  brasDroit.attach(SERVO_BRAS_DROIT);

  fermerPorte();
  brasRepos();

  // LCD
  lcd.begin(16, 2);

  lcd.clear();
  lcd.print("Robot Wall-E");

  Serial.println("Robot Wall-E pret");

  delay(1500);
}

// =========================
// LOOP
// =========================

void loop() {

  long distance = mesurerDistanceCM();

  Serial.print("Distance : ");
  Serial.print(distance);
  Serial.println(" cm");

  afficherLCD(distance);

  // =========================
  // OBSTACLE
  // =========================

  if (distance > 0 && distance <= DISTANCE_OBSTACLE) {

    Serial.println("Obstacle detecte");

    ouvrirPorte();
    brasActifs();

    while (distance > 0 && distance <= DISTANCE_OBSTACLE) {

      tournerDroite();

      delay(100);

      distance = mesurerDistanceCM();

      afficherLCD(distance);

      Serial.print("Nouvelle distance : ");
      Serial.println(distance);
    }

    fermerPorte();
    brasRepos();
  }

  // =========================
  // AVANCE
  // =========================

  else {

    fermerPorte();
    brasRepos();

    avancer();
  }

  delay(50);
}

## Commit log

2026-03-03 Première Modélisation - Porte Avant et Charnière
    [Charnière.3mf, Front Door.3mf]
2026-03-24 Mise à jour du README + ajout d'une modèle représentant la vision globale
    [Vision globale du cube central.f3d, premier-bon-commande.xlsx]
2026-03-25 Ajout Porte w/ pas de vis + structure porte
    Fichier f3d de la porte avec son Pas de vis intégrer version du 24/03/26
    Fichier f3d de la structure de la porte face avant avec espace disponible pour servo moteur sur les coté et passage écran led
    [Front Door 24-03-2026.f3d, Front Door Structure 25-03-2026.f3d]
2026-03-25 Delete Front Door.3mf
    Version obsolète du systeme de porte avant avec une tige intégrale.
    Remplacer par Front Door 24/03/2026.f3d
    [Front Door.3mf]
2026-04-16 Ajout du sol
    [Sol.f3d]
2026-04-16 Ajout du sol au format carré
    [Sol 200x200mm.f3d]
2026-04-17 Nouveaux Blocs Bras
    [Bloc Bras Droit 200-200.f3d, Bloc Bras Gauche 200x200.f3d]
2026-04-21 Rajout des cotés + face avant + portes
    [BBD - 200x200 mm.f3d, BBG - 200x200 mm.f3d, Bloc Bras Droit 200-200.f3d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]
2026-04-21 Correction des noms + suppresion doublon
    [Bloc Bras Droit 200-200.f3d, Bloc Bras Gauche 200x200.f3d, OLD Front Door 24-03-2026.f3d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]
2026-04-27 Ajout du modele de bon commande
    [modele-bon-commande.xlsx]
2026-05-04 Ajustement des décalages des pas de vis
    [BBD - 200x200 mm.f3d, BBG - 200x200 mm.f3d, sol 200x200mm.f3d]
2026-05-04 Réorganisation du repo
    [BBD - 200x200 mm.f3d, BBG - 200x200 mm.f3d, Charnière.3mf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]
2026-05-04 Bloc Arrière + 2eme bon commande
    [Back Structure.f3d, modele-bon-commande.xlsx, premier-bon-commande.xlsx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]
2026-05-05 Partage des fichiers 3mf
    [BBD - 200x200 mm.3mf, BBG - 200x200 mm.3mf, OLD - Sol 200x200mm.f3d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]
2026-05-05 Correction de l'emplacement des pas de vis et des pas de vis
    [Sol 200x200mm.f3d]
2026-05-05 Nouvelle Front Structure
    [Front - Structure.3mf, Front - Structure.f3d]
2026-05-19 Ajout stéréolitographie
    [sol 200x200mm.3mf]
2026-05-19 Ajout du plafond : )
    [plafond 200x200mm.3mf, plafond 200x200mm.f3d]
2026-05-19 Ajout des modèles 3D des blocs pour les bras, il faut refaire le 3mf
    [BBD - 200x200 mm.f3d, BBG - 200x200 mm.f3d]
2026-05-21 Correction des pas de vis
    [BBD - 200x200 mm.f3d, BBG - 200x200 mm.f3d]
2026-05-26 Mise à jour du sol + ajout du boitier des roues
    [boitier_moteur_roue.f3d, sol 200x200mm.3mf]
2026-05-26 head of
    [head of wall-e.f3d]
2026-05-26 Update définitive du sol + boitier moteur
    [boitier_moteur_roue.3mf, boitier_moteur_roue.f3d, sol 200x200mm.3mf]
2026-05-27 Update sol & boitier des roues
    [boitier_moteur_roue.f3d]
2026-05-27 Ajout des fichiers de stéréolitographie
    [BBD - 200x200 mm.3mf, BBG - 200x200 mm.3mf, Face Arrière.3mf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]
2026-05-27 attache coté
    [BBD - 200x200 mm.3mf, BBG - 200x200 mm.3mf, Charnière.3mf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]
2026-05-27 c'est bon le sol ??
    [OLD - Sol 200x200mm.f3d, Sol 200x200mm.f3d, Sol.f3d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]
2026-05-27 ST + renommage
    [OLD - Sol.f3d, OLD Front Door 24-03-2026.f3d, OLD Front Door Structure 25-03-2026.f3d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]
2026-05-27 Ajout des schémas techniques pour le plafond & tête avec le sol & moteurs
2026-05-27 ST Renommage + attache roue
    [attache_roue_4mm_diametres.f3d]
